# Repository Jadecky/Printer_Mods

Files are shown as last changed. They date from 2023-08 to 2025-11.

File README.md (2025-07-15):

# Kyle🇬🇧’s Printer Chaos, Mods & Configs 🛠️
Home to my various mods & QOL Updates for printers I've built, along with config backups.

---

## 🐝 My Printers
|**Name**|**Printer**|**Voron Serial**|**PFA Serial**|**Status**|
|-----|-----|-----|-----|-----|
| **Bee.Zero** | [Voron V0](https://vorondesign.com/voron0.2) | V0.1848 | N/A | On sabbatical (lazy bee vibes) |
| **Bee.Two** | [Micron R1](https://github.com/PrintersForAnts/Micron) | V2.6033 | M.055 | Current Workhorse 🐝 |
| **Bee.Three** | [StealthFork](https://github.com/PrintersForAnts/StealthFork) | SF.xxx | VT.xxxx | Work in Progress |
| **Bee.Four** | FireAnt | V2.xxxx | TBC | In Design Stage 🔥 |
| **Rex 🦖** | [Micron R1 - LDO Beta](https://github.com/PrintersForAnts/Micron) | V2.xxxx | M.202 | Tuning |

---

## 🛠️ Mods & Parts

### - [Micron Things](https://github.com/Jadecky/Printer-Mods/tree/main/Micron%2B)

### - [Voron V0 Things](https://github.com/Jadecky/Printer_Mods/tree/main/V0)

### - [Misc Items](https://github.com/Jadecky/Printer_Mods/tree/main/Misc%20Items)

---

## 🐜 Printers for Ants Items

### - [StealthFork](https://github.com/PrintersForAnts/StealthFork)
The one where Micron & Salad Fork had a baby...

### - [Colony Clacker](https://github.com/PrintersForAnts/ColonyClacker)
Tiny printer? Tiny door? Needs a satisfying clack

---

## 💾 Config Backups

### - [**Micron M.055**](https://github.com/Jadecky/Micron_Configs)

### - **Voron V0.1848** - Still need to setup auto commit 

### - **Micron M.202** - Still need to setup auto commit 

---

Most of these mods are also listed on my [Printables page](https://www.printables.com/@Jadecky3D/models) — if you like what you see, toss me a like or post a make to help me earn that gucci free spool 🧵 and keep the upgrades coming.

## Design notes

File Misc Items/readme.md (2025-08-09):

# Miscellaneous Items

The home of various bits that don't belong to one specific printer — or I just haven’t decided where they live yet.

| **Name** | **Description** |
|---|---|
| [**F623 Bearing Repacker**](https://github.com/Jadecky/Printer_Mods/tree/main/Misc%20Items/F623%20Bearing%20Repacker) | For repacking F623 or other M3 bearings with grease for optimal performance and longevity. |
| [**Micron really useful tool**](https://github.com/Jadecky/Printer_Mods/tree/main/Misc%20Items/Micron%20Really%20Useful%20Tool) | For locating your MGN7 rails & motor pulleys on Micron R1 |

*More random bits will appear here as they get designed or discovered...*

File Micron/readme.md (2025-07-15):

## 🔥 Micron R1 Mods

| **Mod** | **Info** |
|---|---|
| [**Matchstick Mounts**](https://github.com/Jadecky/Printer_Mods/tree/main/Micron/Micron/Matchstick%20Mounts)| MapleleafMakers awesome Matchstick Diffusers, slightly modded to point towards the bed in Micron |
| [**Micron Z Belt Clamp**](https://github.com/Jadecky/Printer_Mods/tree/main/Micron/Micron/Micron%20Z%20Belt%20Clamp)| Belt clamps to allow you to keep a bit of extra Z belt nice & neat. |
| [**ERCF 1515 Mounts**](https://github.com/Jadecky/Printer_Mods/tree/main/Micron/Micron/ERCF%201515%20Mount) | ERCF mounts for 1515 based printers |
| [**Micron Bed Standoff Sleeves**](https://github.com/Jadecky/Printer_Mods/tree/main/Micron/Micron/Micron%20Bed%20Stand%20Off%20Sleeves) | Aesthetic sleeve for your bed standoffs |
| [**Micron Nozzle Scrubber & Purge Bucket**](https://github.com/Jadecky/Printer_Mods/tree/main/Micron/Micron/Micron%2B%20Bambu%20Nozzle%20Scubber_with%20Purge%20Bucket) |
| [**Skirt Centre Accent Single Piece**](https://github.com/Jadecky/Printer_Mods/tree/main/Micron/Micron/Skirt%20Accent%20Single%20Piece)| 3x centre accent pieces merged into one for slightly cleaner look |
| [**Stealth Fan Grill**](https://github.com/Jadecky/Printer_Mods/tree/main/Micron/Micron/Stealth%20Fan%20Grills) | Slight modification to the stock Micron+ Fan Grills, reducing the visible accent areas for a more subtle, stealthy look |
| [**R1 Spool Holder Dual Colour**](https://github.com/Jadecky/Printer_Mods/tree/main/Micron/Micron/R1%20Spool%20Holder_Dual%20Colour) | Spool holder with accent PFA logo. |
| [**Display Bezel Accent Border**](https://github.com/Jadecky/Printer_Mods/tree/main/Micron/Micron/Display%20Bezel%20Border%20Accent) | Bezel for 4.3 display with small accent on the border and accent logo insert. For those who prefer less accent |

---

## 🕰️ Legacy Items - Micron R0

| **Mod** | **Info** |
|---|---|
[**3DPF**](https://github.com/Jadecky/3DPF/tree/main)|Carbon Filter/Bed Fan that fits between the bed extrusions. Now stock on Micron R1
[**KGLM Hex Z-Joint**]()|A slightly chonkier Z Joint to prevent cracking. Half hex shaped, rather than spherical. With Micron Logo or without.
[**MDC**]()|Magnetic Door Corners - Chonky Door corners/hinges to prevent your Micron door falling off. Uses screws/heatsets or optional VHB variant. Has a magnet in each corner to keep the door closed. 
[**Smol Hex Skirts**]()|Micron+ skirts with scaled down Hex's. 3.5" & 4.3" display & no display variants. Dual Keystone rear option.
[**Z Drive Belt Covers with Cable Access**]()|Allows cables for things such as Cameras or LEDs to be run down the extrusions and neatly through the Z Drive cover into the electronics bay.

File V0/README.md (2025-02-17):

## Various Voron V0 mods and things
Mod|Info
----|----
Rear DIN Rail Mount|As per title.. a DIN Rail mount for the rear of your V0, becuse VHB is nasty. 
Lower DIN Rail Mount|Again.. as per title, a DIN Rail Mount for the lower section of your V0, because VHB is grim. 
UHP Mount|Screw in mounts for a UHP200/24 for your V). Still allows bottom panel, because screw you VHB.

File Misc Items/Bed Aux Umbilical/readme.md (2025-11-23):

### Bed Aux Umbilical ###

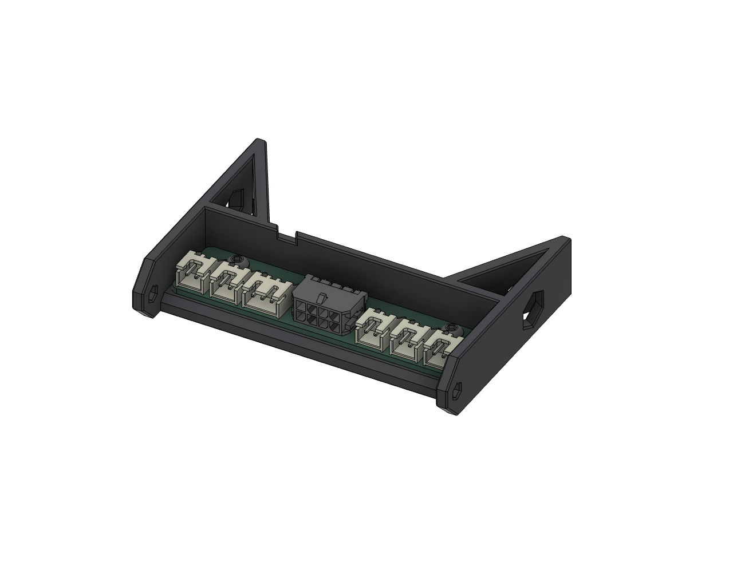
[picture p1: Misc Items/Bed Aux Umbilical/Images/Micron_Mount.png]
MicronMount


Originally designed for Micron R1, with a corresponding mount that replaces the Wago mount on the filter. 

These are included in the LDO Micron R1 Kit.

More information to follow.

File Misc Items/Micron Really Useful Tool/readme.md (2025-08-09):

# Really useful tool for locating MGN7 Rails and motor pulleys for Micron R1

### A / B Motor Pulleys

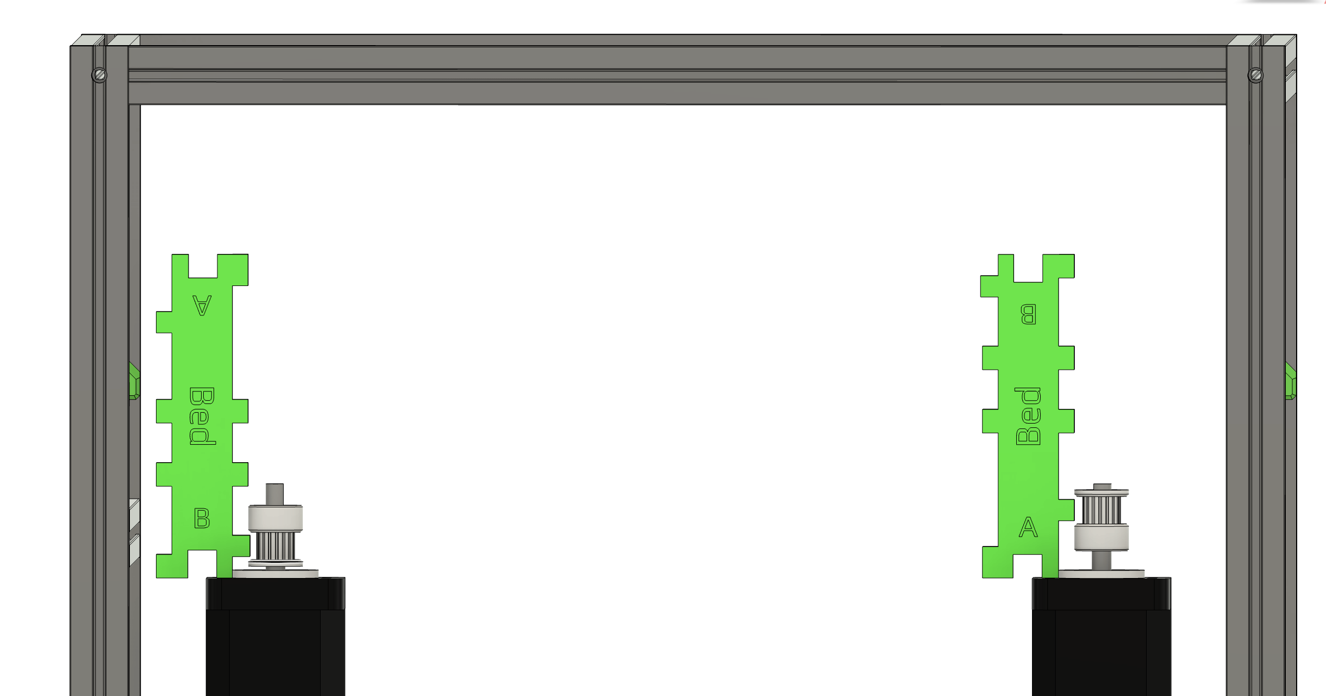
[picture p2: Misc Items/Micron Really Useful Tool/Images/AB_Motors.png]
AB Motor Pulley Example


### Z Motor Pulleys

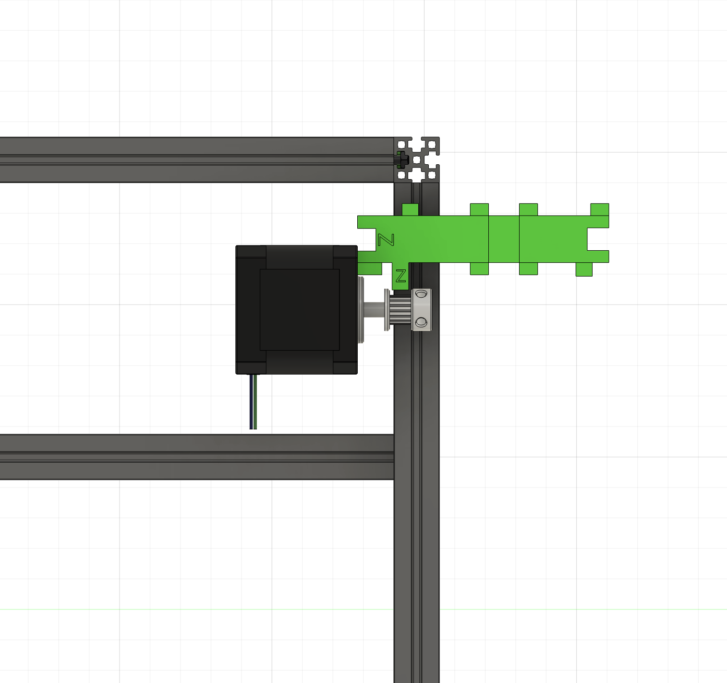
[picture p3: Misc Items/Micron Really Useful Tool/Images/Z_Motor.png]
Z Motor Pulley Example


### Y Rail

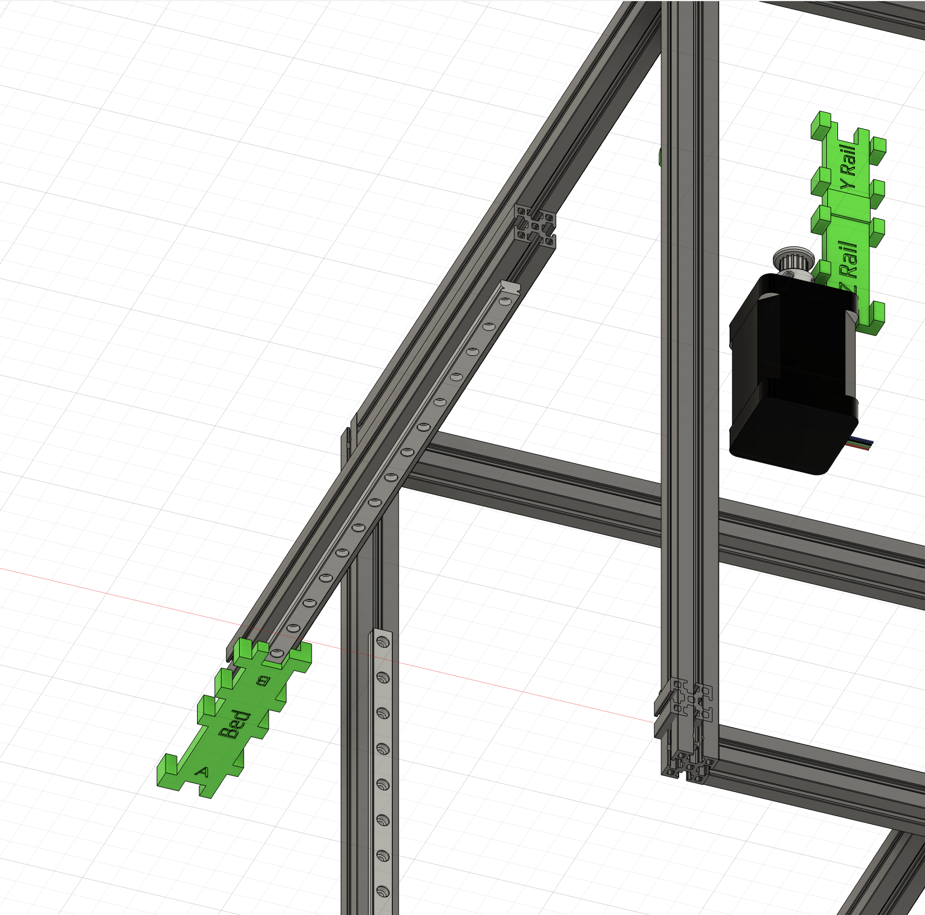
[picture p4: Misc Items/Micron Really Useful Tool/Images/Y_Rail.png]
Y Rail Example


### Z Rail

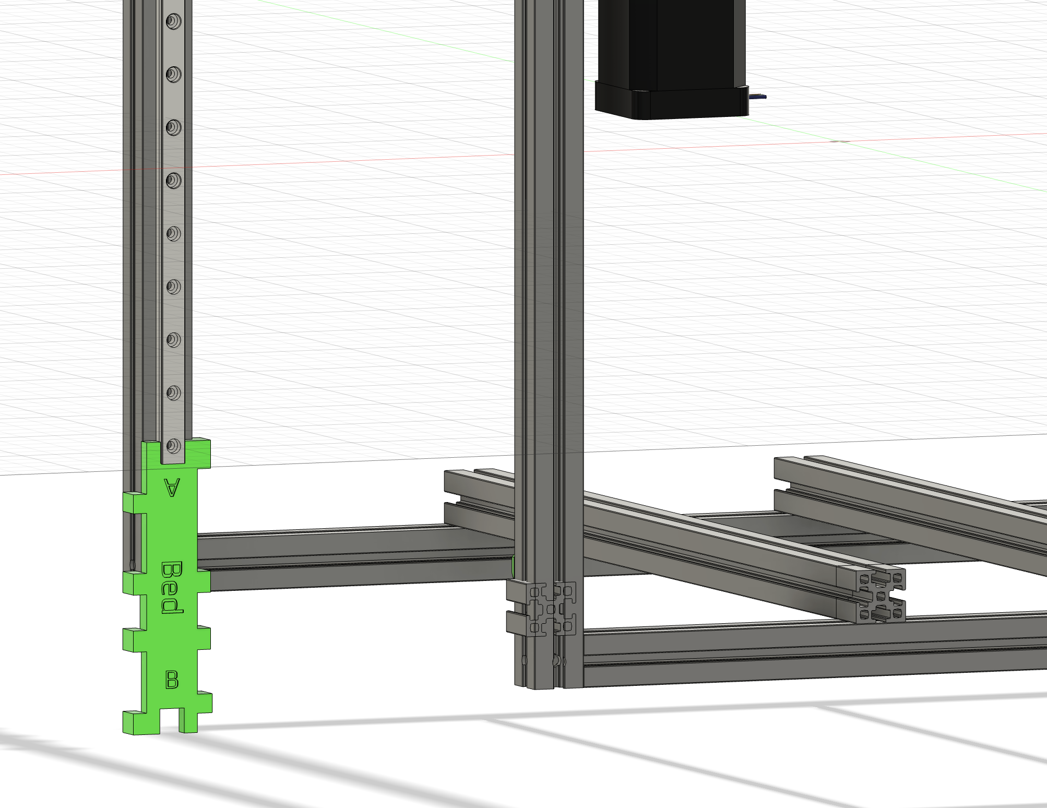
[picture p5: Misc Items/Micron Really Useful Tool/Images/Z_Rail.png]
Z Rail Example


### Bed Extrusion Location

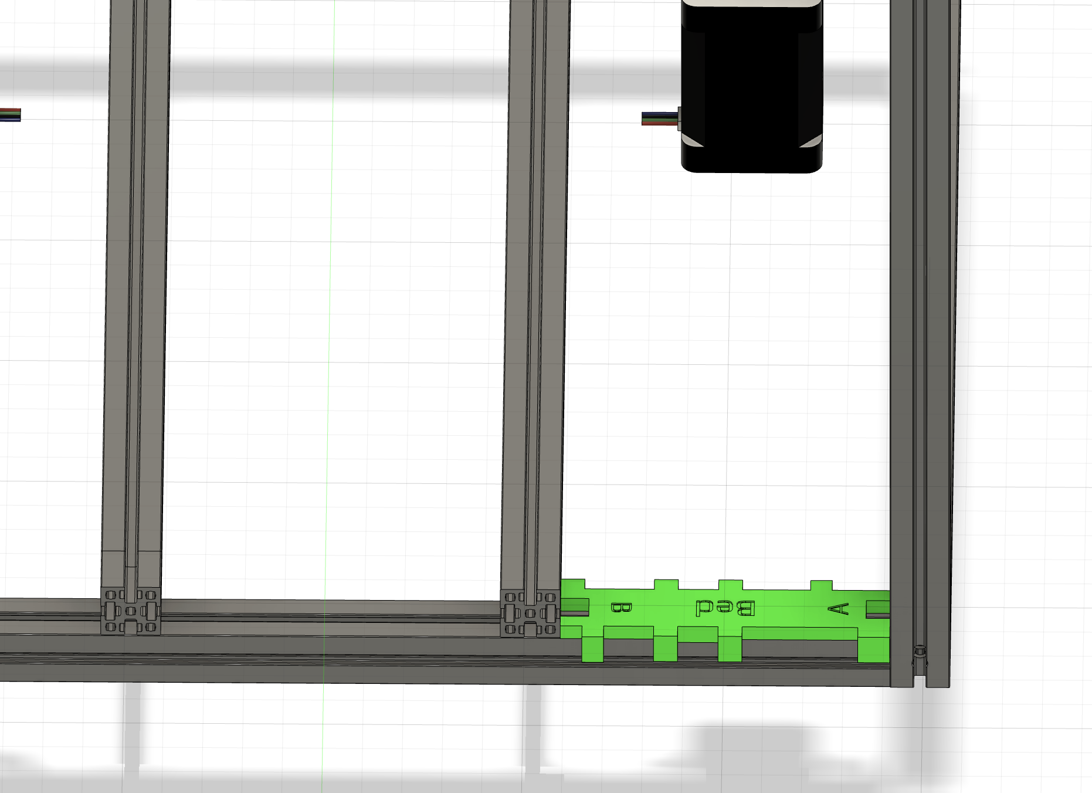
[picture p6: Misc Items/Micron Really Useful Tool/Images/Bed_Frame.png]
Bed Frame Example


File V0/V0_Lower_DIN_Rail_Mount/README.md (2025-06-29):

## Lower DIN Rail Mount for the Voron V0.2

Utilises the existing M3 Nut and hole for mounting the skirt. 

Can be mounted in upto 3x different locations, using the different skirt mounts. 

Has an optional tension screw to prevent rattling of the DIN rail.

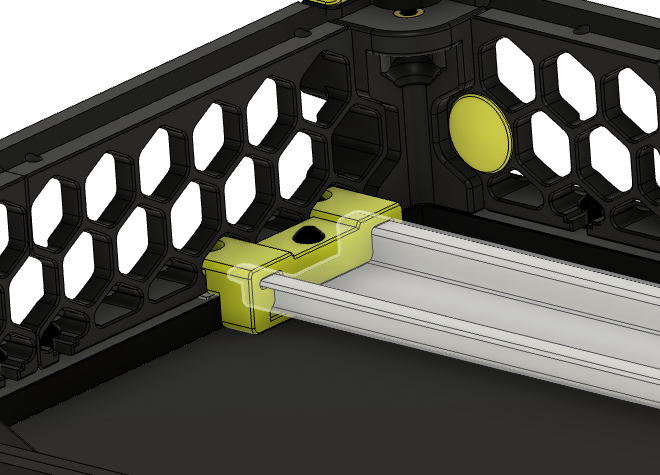
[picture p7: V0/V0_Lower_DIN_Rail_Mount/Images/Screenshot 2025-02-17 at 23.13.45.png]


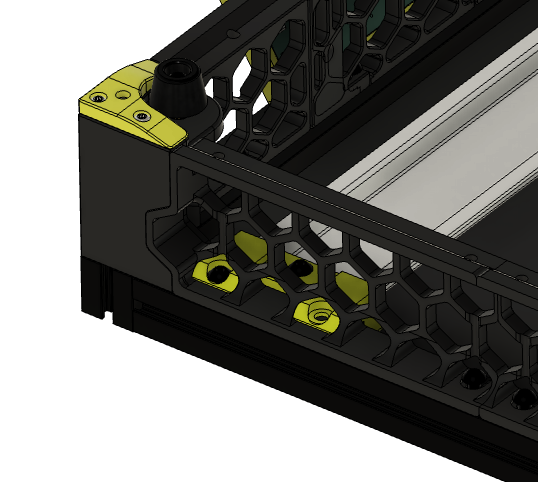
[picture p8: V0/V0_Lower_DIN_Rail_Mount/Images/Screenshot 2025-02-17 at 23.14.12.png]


## BOM
Qty|Item|Links/Comments
---|----|---
6x|M3x8 BHCS|[AliExpress](https://s.click.aliexpress.com/e/_Ezk8fMo)
1x|M3 Threaded Heatset Insert|[AliExpress](https://s.click.aliexpress.com/e/_ExdRmeo)
1x|DIN Rail 195mm|[AliExpress](https://s.click.aliexpress.com/e/_EHIRMhQ)

## Printing
Print using Voron standard print settings.

Parts are orientated in the correct orientation.

No Supports required. 

## Version History

### 17-Feb-2025
Initial Upload

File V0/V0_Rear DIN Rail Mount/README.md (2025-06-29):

## Rear DIN Rail Mount for the Voron V0

Initially based on [Chirpy's DIN Rail Mount](https://github.com/chirpy2605/voron/tree/main/V0/v0.2_Stuff#din-rail-mounts)

Added more stealth, more bestagons, and optional tension screw to prevent rattling of the rail. 

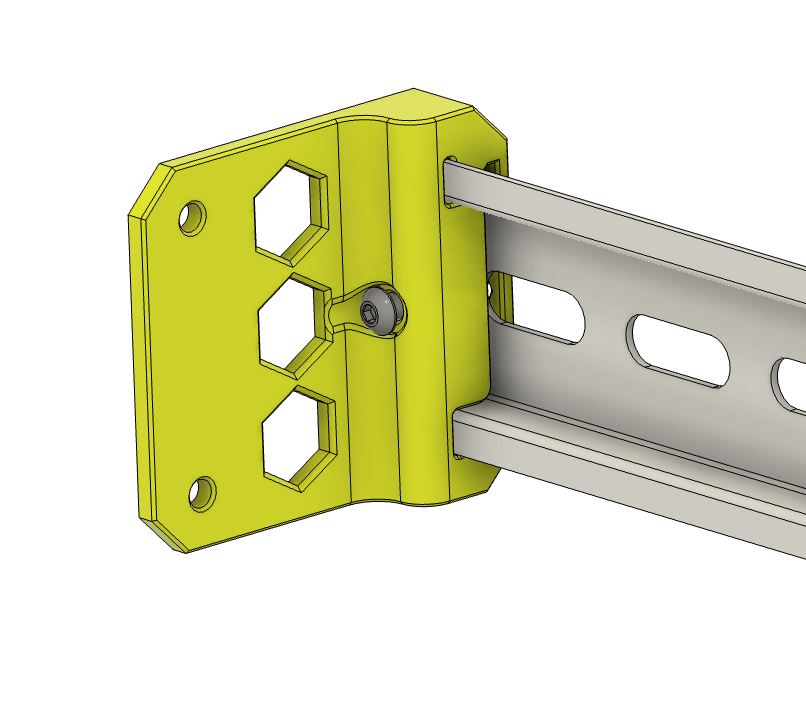
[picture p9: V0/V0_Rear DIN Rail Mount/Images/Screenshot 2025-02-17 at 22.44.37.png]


## BOM
Qty|Item|Links/Comments
---|----|---
4x|M3x8 BHCS|[AliExpress](https://s.click.aliexpress.com/e/_Ezk8fMo)
2x|M3x12 BHCS|[AliExpress](https://s.click.aliexpress.com/e/_EuzIPxm)
2x|M3 Threaded Heatset Insert|[AliExpress](https://s.click.aliexpress.com/e/_ExdRmeo)
1x|DIN Rail 195mm|[AliExpress](https://s.click.aliexpress.com/e/_EHIRMhQ)

## Printing
Print using Voron standard print settings.

Parts are orientated in the correct orientation.

No Supports required. 

## Version History

### 17-Feb-2025
Initial Upload

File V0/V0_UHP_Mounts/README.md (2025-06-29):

## UHP 200/24 PSU Mount for Voron V0

### Allows you to mount a UHP 200/24 without the need for VHB, whilst still being able to 110% complete your printer with a bottom panel. 

Utilises the existing M3 Nut and hole for mounting the skirt. 

Can be mounted in upto 3x different locations, using the different skirt mounts. 

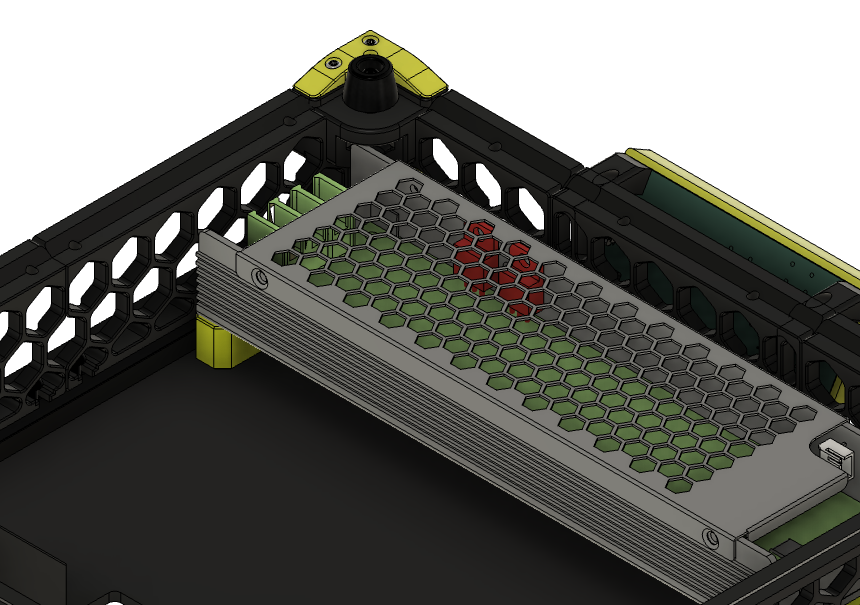
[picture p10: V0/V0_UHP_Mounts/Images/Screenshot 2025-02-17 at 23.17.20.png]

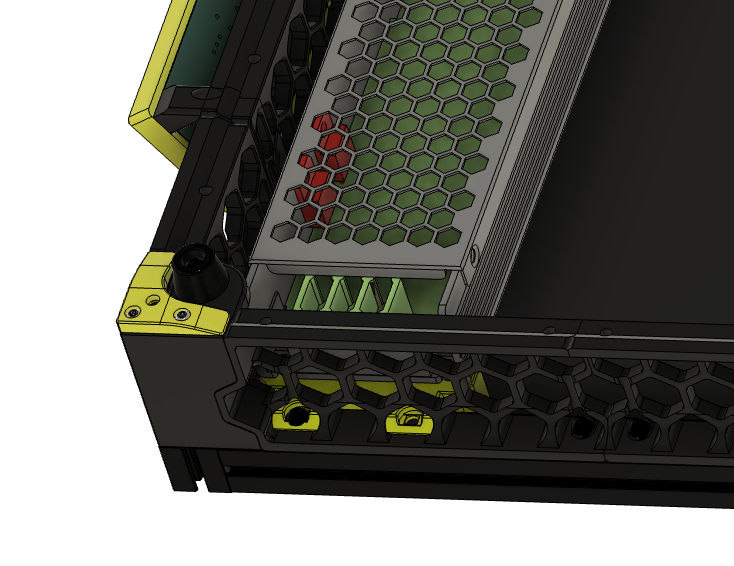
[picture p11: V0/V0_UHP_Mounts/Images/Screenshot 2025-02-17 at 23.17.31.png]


## BOM
Qty|Item|Links/Comments
---|----|---
4x|M3x12 or M3x14 BHCS|[AliExpress](https://s.click.aliexpress.com/e/_EuzIPxm)
4x|M3 Threaded Heatset Insert|[AliExpress](https://s.click.aliexpress.com/e/_ExdRmeo)
1x|DIN Rail 195mm|[AliExpress](https://s.click.aliexpress.com/e/_EHIRMhQ)

## Printing
Print using Voron standard print settings.

Parts are orientated in the correct orientation.

No Supports required. 

## Version History

### 17-Feb-2025
Initial Upload

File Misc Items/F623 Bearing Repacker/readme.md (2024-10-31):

## F623 Bearing Repacker
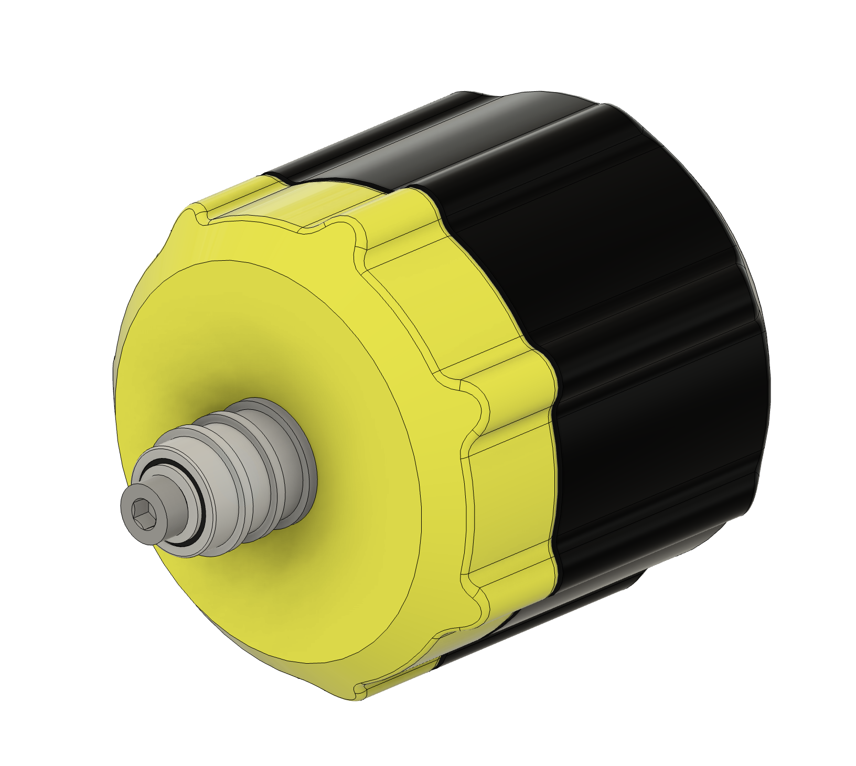
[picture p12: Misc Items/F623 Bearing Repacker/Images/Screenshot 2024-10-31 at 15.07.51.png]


'Remix' of the original [Bearing Repacker](https://github.com/Annex-Engineering/Misc_Designs/tree/master/Bearing_Repacker) from [Annex-Engineering](https://annex-engineering.eu) for the smaller F623 Bearings found in the Voron V0 and 3D Printers for Ants. 

Now has an M3 heatset, rather than a nut, to prevent unwanted handling of grease covered, sticky nuts. 
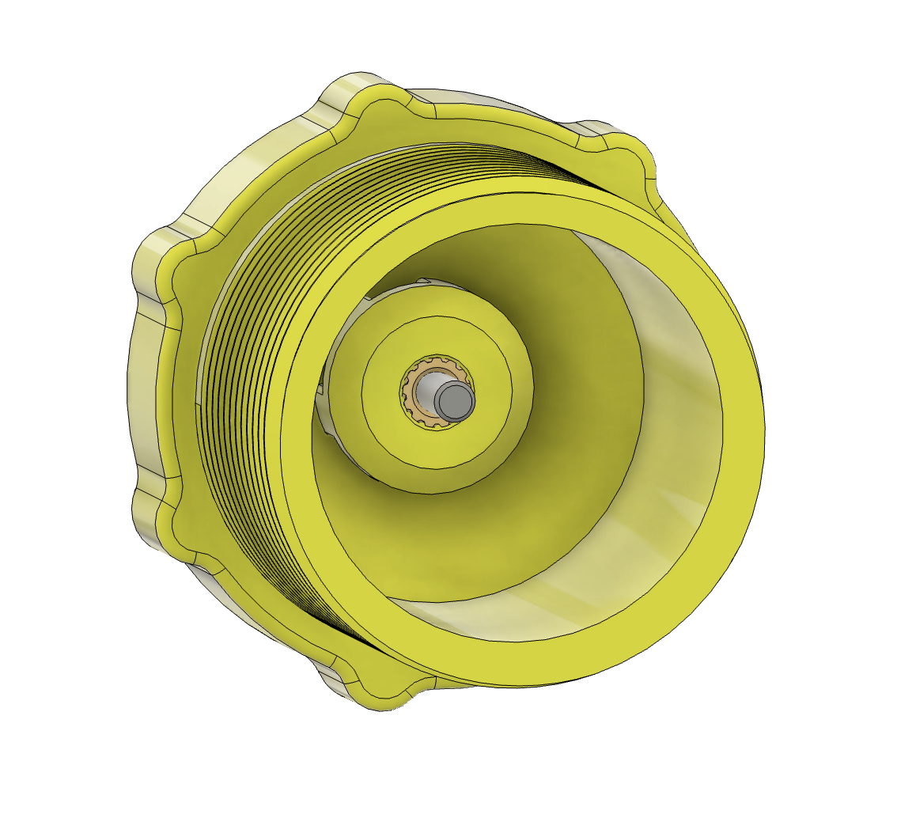
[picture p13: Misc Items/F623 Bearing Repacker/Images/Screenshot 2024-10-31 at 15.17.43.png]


If using a flanged bearing, the flange should go against the printed part. (See first image)

Don't forget to remove and replace the seals before and after repacking withgrease.

# BOM
Qty|Item|Notes
---|----|---
1x|`Top_x1.stl`|
1x|`[a]_Bottom_x1.stl`|
1x|M3x30SHCS|Length varies depending on number of bearings
1x|M3 Heatset|
1x|M3 Shim Washer|Optional, but nice between the SHCS and the Bearing
Nx|Grease of choice
Nx|F623 Bearings|or similar M3 bearings
Nx|Gloves|Horrible stuff is grease.

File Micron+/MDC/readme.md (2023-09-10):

# MDC - Magnet Door Corners
Chonky door hinges & corners that are mounted with screws, and have a magnet in each corner.

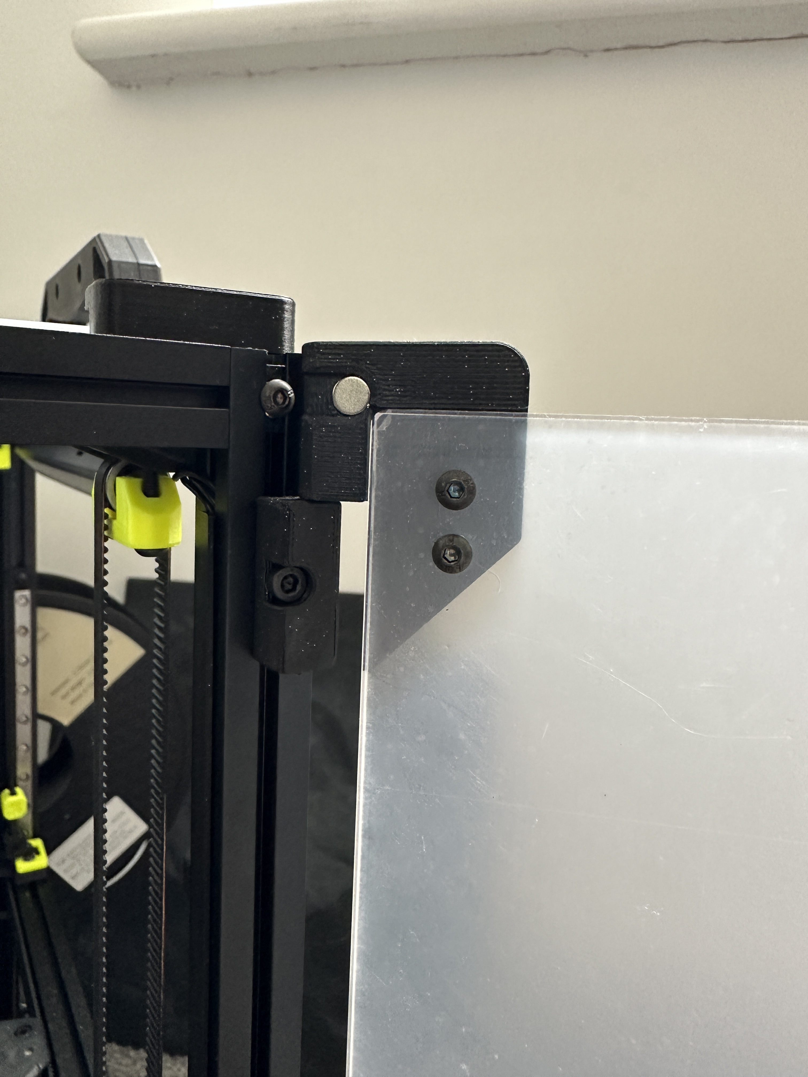
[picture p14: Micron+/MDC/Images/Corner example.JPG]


## Disclaimer

**The primary design of this modification requires you to drill your door panel. Drill guides have been provided.**

**Whilst every effort has been made to ensure this goes as smoothly as possible, it is your responsibility to measure and double check before adding holes to your panel. Please check, double check, and tripple check prior to drilling.**

**If you aren't comfortable/confident enough to drill your panel, there is a DXF so you can get one cut, there is also a VHB version, although this is currently untested.**

## Why is this a thing?

There are several reasons this modification has come about:

- I needed to use the left extrusion to feed cables to the camera, you can't do this with the stock magnet holders being screwed to that extrusion. This modification puts a magnet in each corner instead.

- There were several reports of the larger Micron+ door falling off due to the small contacct area for VHB tape on the stock hinges.

- My OCD likes each corner on the front to look the same. The new hinges have taken the same design as the left hand corners of the door.

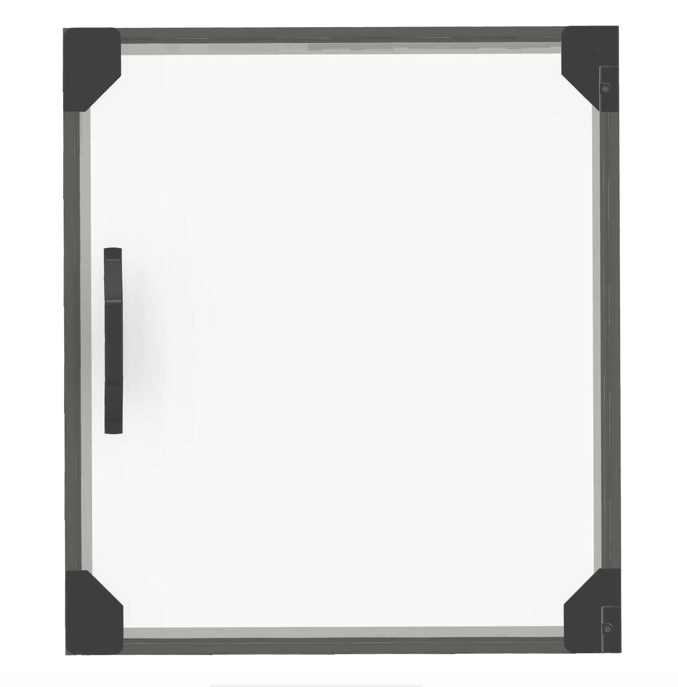
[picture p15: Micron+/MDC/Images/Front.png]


## BOM
Qty |Part|Notes
---|----|---
1x|1mm / 1.5mm drill bit|For drilling pilot holes in the panel
1x|3mm drill bit|For finialising the holes in the panel
10cm|Masking/painters tape|For marking the centre of the panel for drilling the handle holes 
4x|6x3 Magnets|N52 recommended for a nice grab 
2x|M3x8mm SHCS|To mount the hinges to the frame
13x|M3x6mm BHCS|10x for mounting printed parts to door, 3x for magnets in TL, TR & BL corners. *(If using VHB, only 3x required)*
10x|M3 Washer|Optional, but good practice when mounting the printed parts to door panel
10x|Voron Spec Brass Heatset Inserts|M3x5Dx4.5W *(Not required for VHB version)*
2x|M3x35 *minimum* BHCS|For hinges, M3x40, M3x45 will also work
1x|M3x4mm|For BR Magnet. Unfortunately anything larger will interfere/mark the extrusion.
6x|M3 Nut|4x for corner magnets, 2x for mounting hinges to frame. 

## Printed Parts BOM
**Heatset Version**
Qty|STL
---|---
1x|Bottom_Hinge_Door_Mount
1x|Bottom_Left_Door_Corner
1x|Heatset_Door_Handle
2x|Hinge_Frame_Mount
1x|Top_Hinge_Door_Mount [*]
1x|Top_Hinge_Door_Mount_MMU [*]
1x|Top_Left_Door_Corner
**Drill Guides**
1x|Drill_Guide_BL
1x|Drill_Guide_BR
1x|Drill_Guide_Handle
1x|Drill_Guide_TL
1x|Drill_Guide_TR

[*] Choose either/or

**VHB Version**
Qty|STL
---|---
Qty|STL
2x|Hinge_Frame_Mount
1x|VHB_Bottom_Hinge_Door_Mount
1x|VHB_Bottom_Left_Corner
1x|VHB_Top_Hinge_Door_Mount [*]
1x|VHB_Top_Hinge_Door_Mount_MMU [*]
1x|VHB_Top_Left_Corner

[*] Choose either/or

## Drill Guides

You should use a 1mm/1.5mm pilot drill initially, then move up to a 3mm drill bit. 

Drill slowly without too much pressure, let the drill bit do the work, and ensure you have a solid base such as a piece of wood. This should prevent cracking your panel. 

The drill guides are marked with which corner they should be placed. They go in the same orientation as the hinges, so facing you when looking at the front.

**Flat Surface | Panel | Drill Guide.**

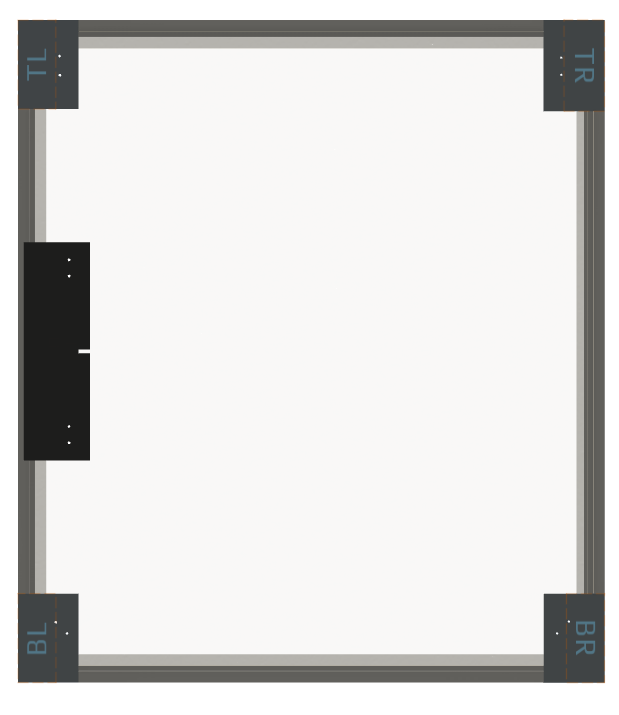
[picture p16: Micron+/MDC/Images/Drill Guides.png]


When locating the handle drill guide, use a piece of masking tape (mine still has the protective film on below) to mark the centre line. There is a recess in the drilling guide that will line up with this centre line:

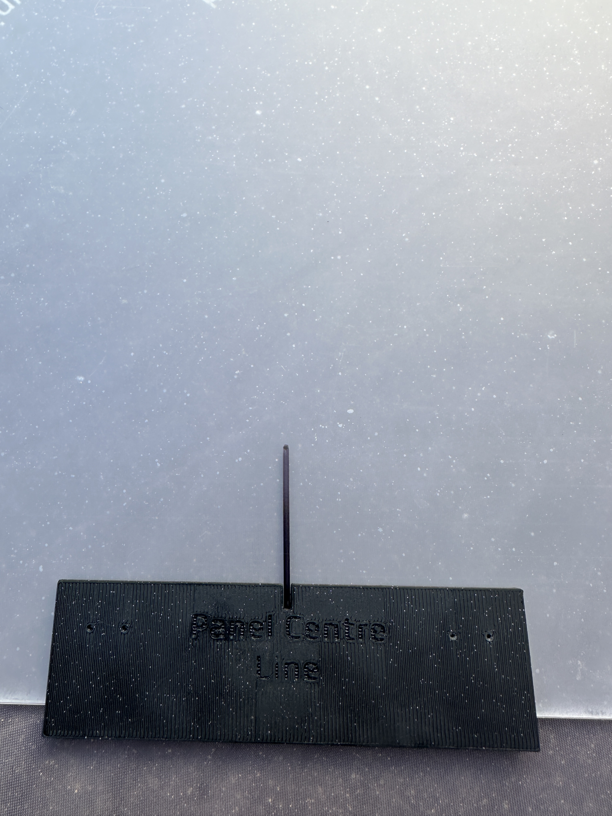
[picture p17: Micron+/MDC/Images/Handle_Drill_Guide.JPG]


## Mounting to the printer

Each corner piece has a recess for 1 6x3 magnet, and 2x holes for a voron spec heatset insert. 

- Insert the 2x heatsets into each corner, and the 4x heatsets into the handle. (If using VHB version only the magnets are required).

(I suggest sticking the magnet to the end of a screw, then using the screw to push the magnet home).

Glue shouldn't be required, but you can add a drop of CA/Super glue, should you wish to.

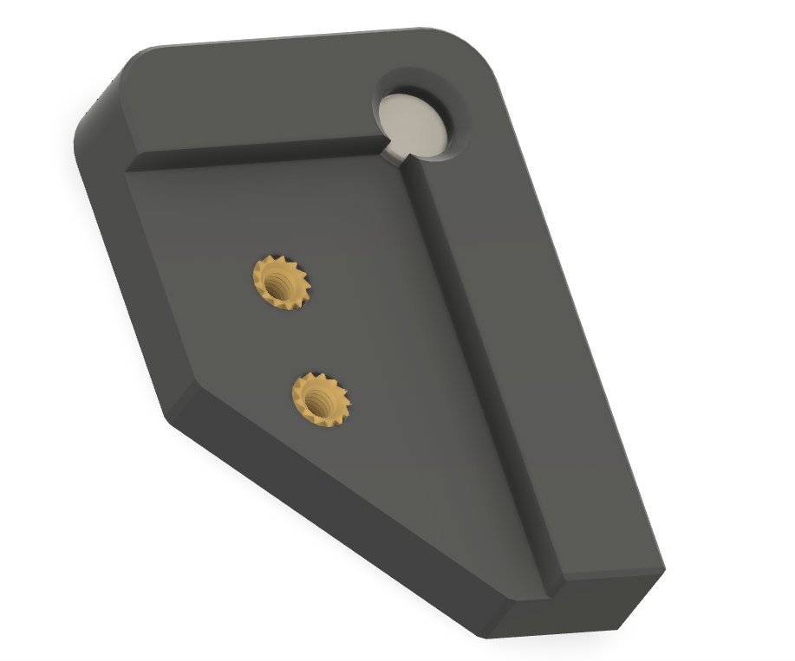
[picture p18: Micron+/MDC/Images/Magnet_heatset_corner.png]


- Insert an M3x35mm *minimum* screw into the the bottom of the hinge_frame_mount. (Anything upto M3x45 can be used here).

- Mount the lower Hinge_Frame_Mount to the right extrusion using an M3x8 SHCS & M3 Nut, leave loose for now. 

- Insert an M3 Nut with an M3x4mm BHCS, above the Lower hinge_frame_mount. This will be used to hold the door closed with the magnet you just inserted for the hinge.

- Now repeat fot the top hinge. (Upto an M3x10mm BHCS can be used for the magnets on TL, TR & BL corners as the screw will go through the access hole in the extrusion).

- Place the ```bottom_hinge_door_mount``` & ```top_hinge_door_mount``` over the relevant ```hinge_frame_mount``` and align the screws in the extrusion with the magnets.

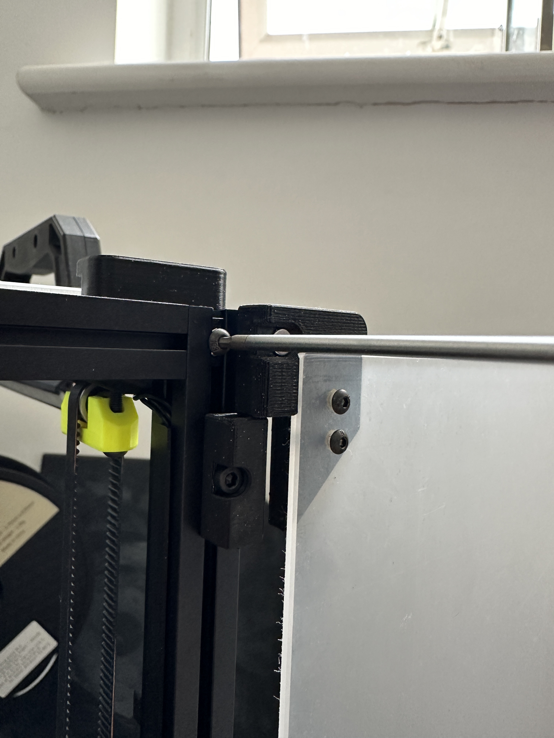
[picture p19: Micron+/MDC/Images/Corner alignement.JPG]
 

- Repeat the M3 BHCS twice on the left extruision and align with the TL & BL corners.

- Mount the printed pieces to the door using M3x6mm BHCS and an optional M3 Washer.

- Check alignment of your hinge mounts and magnet screws and tighten everything up. 

# Feedback

I have added this to my printer without any issues. @Staticanime has also tested this without issue. If you have any feedback/advice please discuss in the [kyle_gb channel](https://discord.com/channels/825469421346226226/1132795892810907748) on the [Doomcube Discord.](https://discord.gg/doomcube)

# To Do / Change Log
- Add hardware to CAD
- Tidy up CAD

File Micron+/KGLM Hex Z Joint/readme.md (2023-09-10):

# KGLM Hex Z-Joint

A slightly chonkier Z Joint to prevent cracking. Half hex shaped, rather than spherical. With Micron Logo or without.

(For the logo version, print the top layer slooooow)

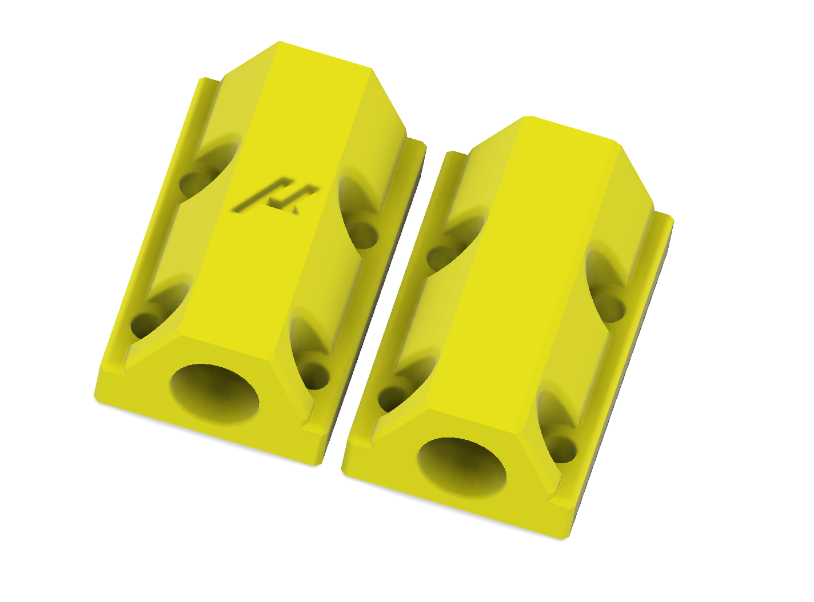
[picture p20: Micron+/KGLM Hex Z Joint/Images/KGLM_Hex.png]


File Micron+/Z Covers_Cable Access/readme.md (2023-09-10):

# Z Drive Belt Covers with Cable Access

Allows cables for things such as Cameras or LEDs to be run down the extrusions and neatly through the Z Drive cover into the electronics bay. 

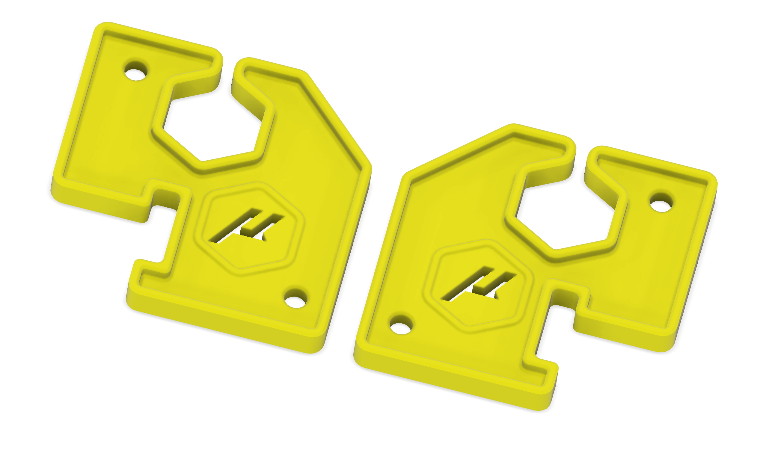
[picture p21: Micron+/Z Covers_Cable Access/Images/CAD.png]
CADIMAGE


Modelled here by @staticanime

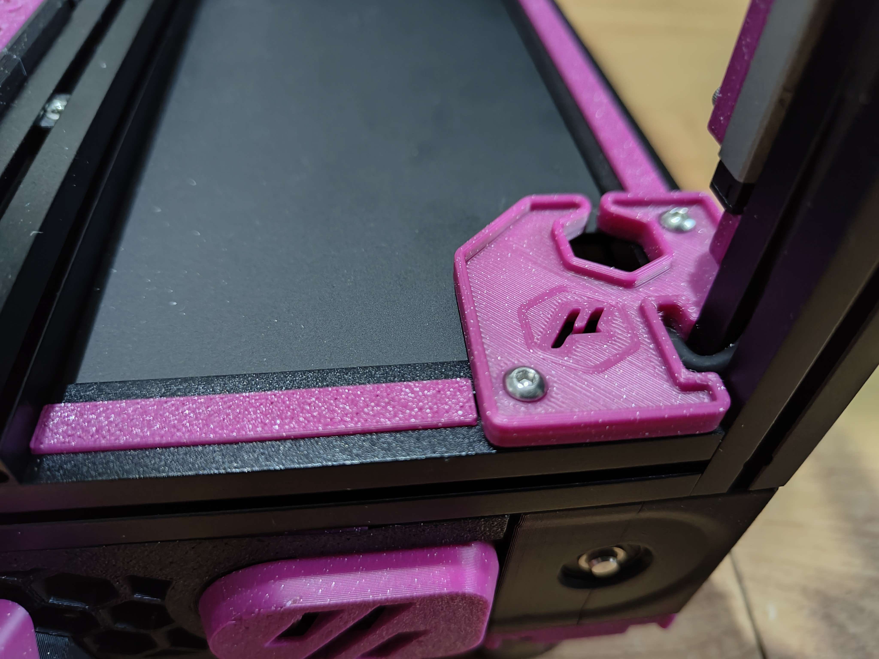
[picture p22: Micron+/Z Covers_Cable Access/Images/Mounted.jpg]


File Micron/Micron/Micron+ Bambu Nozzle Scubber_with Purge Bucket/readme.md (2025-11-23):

# 🧽 Micron+ Nozzle Scrubber & Purge Bucket  
### *Because even your nozzle deserves a spa day.*

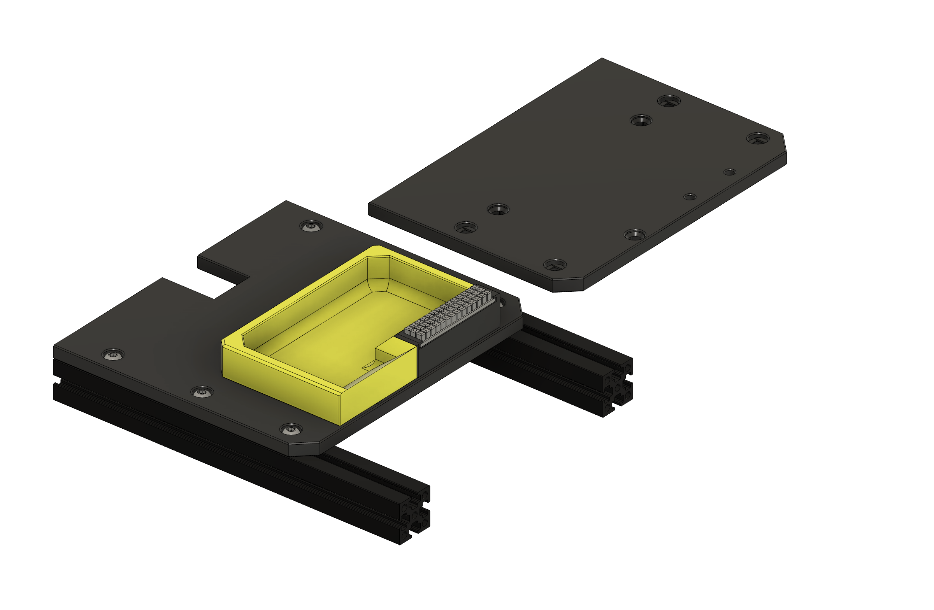
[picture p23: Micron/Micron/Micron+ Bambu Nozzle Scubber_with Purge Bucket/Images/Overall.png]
Overall View


Keep your nozzle tidy and your purge blobs contained with this magnetic bucket and silicone scrubber combo — easy to install, easy to empty, and deeply satisfying to use.

Now available with the silicone brush on right (original) or left. Placing it on the left reduces any fouling of the toolhead on the Z Chain.
Thanks to `@vince M.213` for the suggestion to have the new brush on the left variant. 

There is also a different version of the Bucket, and Brush holder for LDO kits as they come with 15mm standoffs for the bed rather than M4 Knurled nuts. 

**IMPORTANT** If using the brush on the left variant, you will need to adjust the co-ordinates in the provided macros if you are using them. 
---

## 🧼 Features  
- 🐜 Designed for **Micron+** 
- 🧲 **Magnet & screw bucket fitment** for secure mounting and quick removal  
- 🧽 Uses **Bambu Lab A1-style silicone nozzle scrubber**  
- ⚙️ 3x base options included: `base_no_chain`, `base_boop`, & `base_stock` for flexible installs

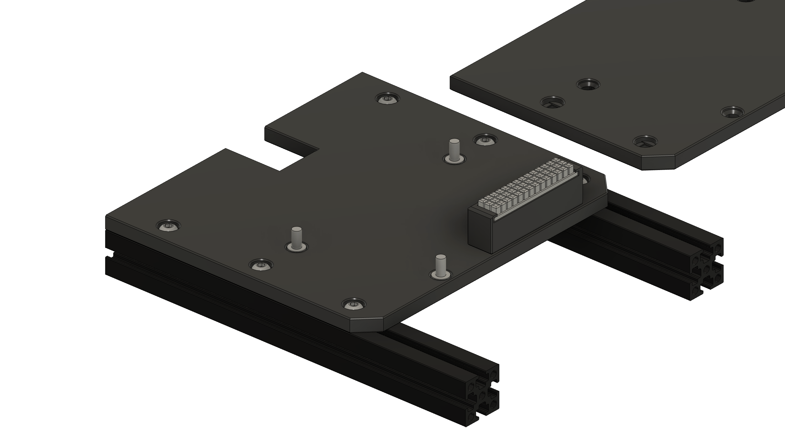
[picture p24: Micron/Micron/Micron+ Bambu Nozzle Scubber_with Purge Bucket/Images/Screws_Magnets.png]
Screws & Magnets


---

## 📦 Bill of Materials (BOM)

| Qty | Item | Notes / Link |
---|----|----
x7|M3x6 BHCS|[Aliexpress](https://s.click.aliexpress.com/e/_EuZgLr4)
x6|M3 Hex Nuts|[Aliexpress](https://s.click.aliexpress.com/e/_EwAgnb8)
x6|6mm x 3mm N52 Magnet|[Aliexpress](https://s.click.aliexpress.com/e/_EQ4GZeE)
x2|4x5 Heatset Insert (Voron spec)|[Aliexpress](https://s.click.aliexpress.com/e/_EuBQ66m)
1x|Bambu Lab A1 Nozzle Scrubber|[Aliexpress](https://s.click.aliexpress.com/e/_Ev16llx)

---

## 📅 Version History

### 23-Nov-2025
- Added `Brush_Holder_LDO_Kit_x1.stl` and `[a]_Bucket_LDO_Kit_x1.stl` for use with LDO Micron R1 Kits
- Added new variat with the brush on the left, rather than the right
- Updated CAD to include the above changes, now v15

### 16-Jun-2025
- Added `base_stock.stl` for stock Micron bed location
- Redesigned front edge with better cleance for earth cables screwed to build plate
- Reduced mountnig screws from x6, to x4
- Relocated rear mounting screws, to allow use of stock printed bed extrusion mounts, or extended 1515 extrusions
- Typo in `nozzle_poop.cfg` corrected
- Updated CAD to v13

### 05-Jun-2025
- Added `nozzle_brush.cfg`
- Added `nozzle_poop.cfg`

### 20-Nov-2024  
- Initial release  
- Added `base_no_chain.stl` for alternate setups  

---

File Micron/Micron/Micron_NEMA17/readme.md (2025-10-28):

# NEMA17 A/B Motor Upgrade for you Micron

Overall View

---

## 🔧 Overview 
New A/B motor mounts for your Micron, that are designed to use NEMA17 motors, with accompanying dual sheer bearing holders. 
Full bed travel is retained, however you might need to readjust the location of your bed towards the front slightly. (Approx 4mm)

Bearing mount retainers can be found in the Micron repo **[here](https://github.com/PrintersForAnts/Micron/tree/main/STLs/Gantry/AB_Drives/double_shear_mounts)**

---

## 🪛 Changes from Stock
- Bearing Mounts require 2x **M3x30 SHCS**
- A/B Support Extrusion requires shortening slightly to **168mm**

---

## 🖨️ Print Settings  

**All STLs should be pre-oriented for printing.**

- **Material:** ABS or ASA
- **Layer height:** 0.20 mm (including first layer)
- **Wall count:** 4
- **Extrusion width:** 0.40 mm (forced)
- **Top/bottom solid layers:** 5
- **Infill:** 40% (Grid, Gyroid, Honeycomb, Triangle, or Cubic)
- **Supports:** Not required

---

## 🗓️ Version History  

### 28 Oct 2025  
- 🆕 Initial release  

---

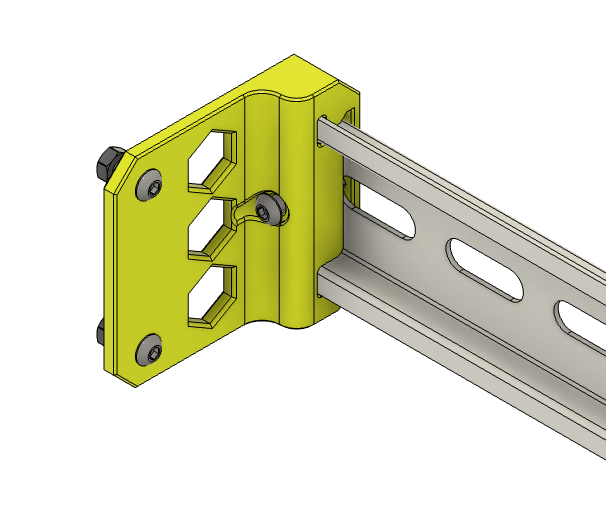
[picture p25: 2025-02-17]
V0/V0_Rear DIN Rail Mount/Images/Screenshot 2025-02-17 at 22.47.20.png

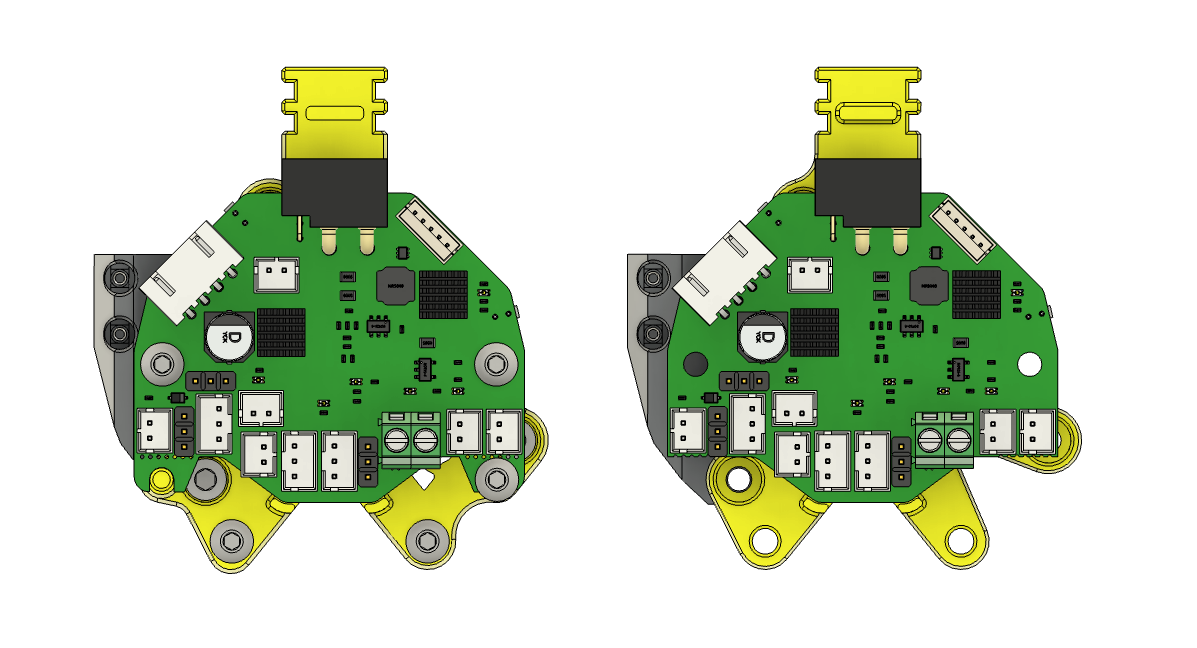
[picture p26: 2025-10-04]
Micron/Micron/AntHead_NH36 Mount/Images/Tabs_NoTabs.png

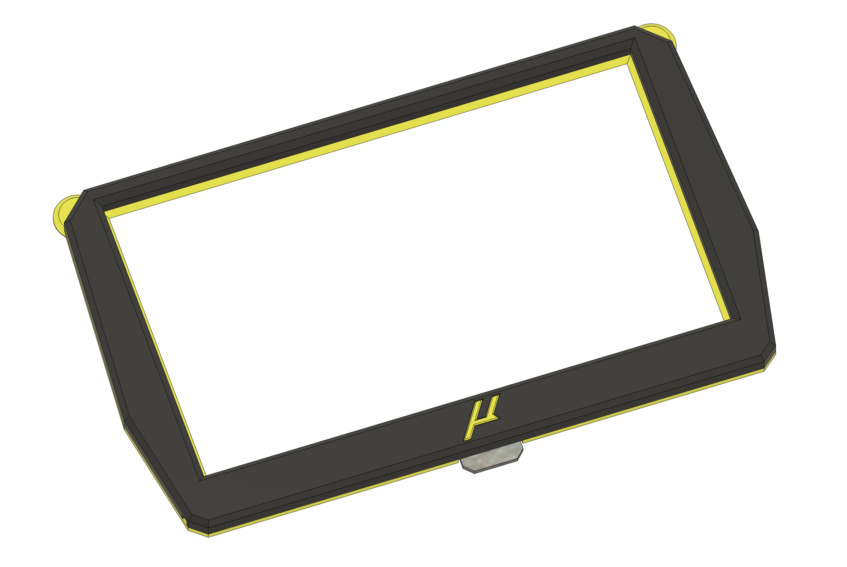
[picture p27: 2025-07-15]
Micron/Micron/Display Bezel Border Accent/Images/CAD.png

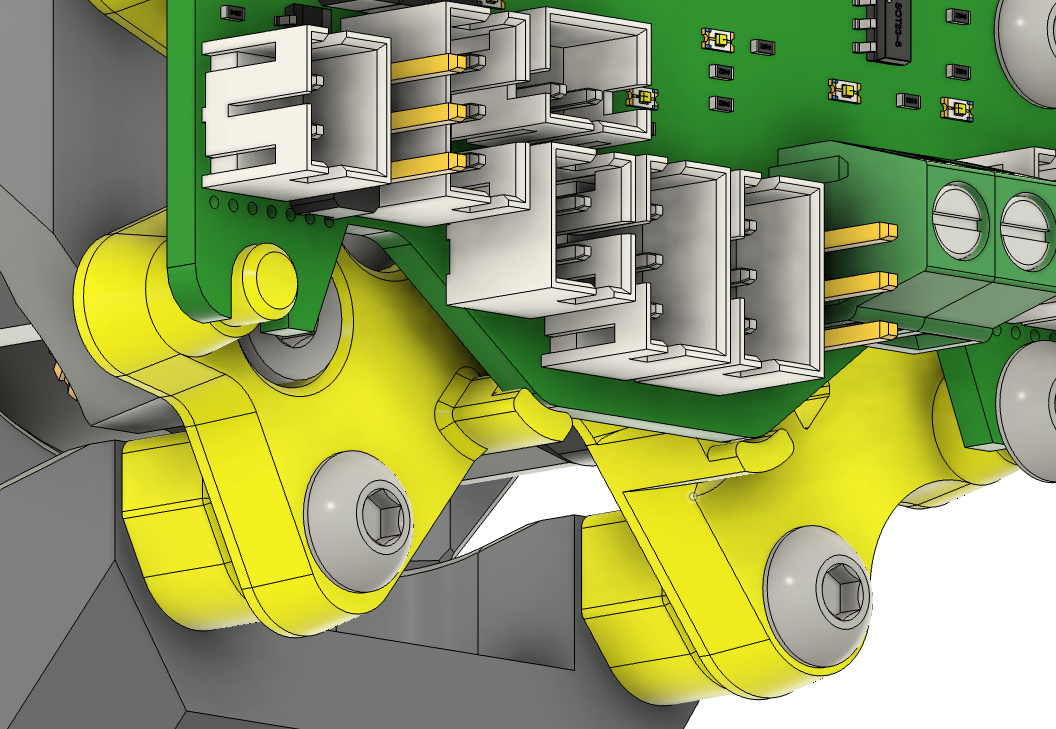
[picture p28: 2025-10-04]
Micron/Micron/AntHead_NH36 Mount/Images/Built_in_support_lower.png

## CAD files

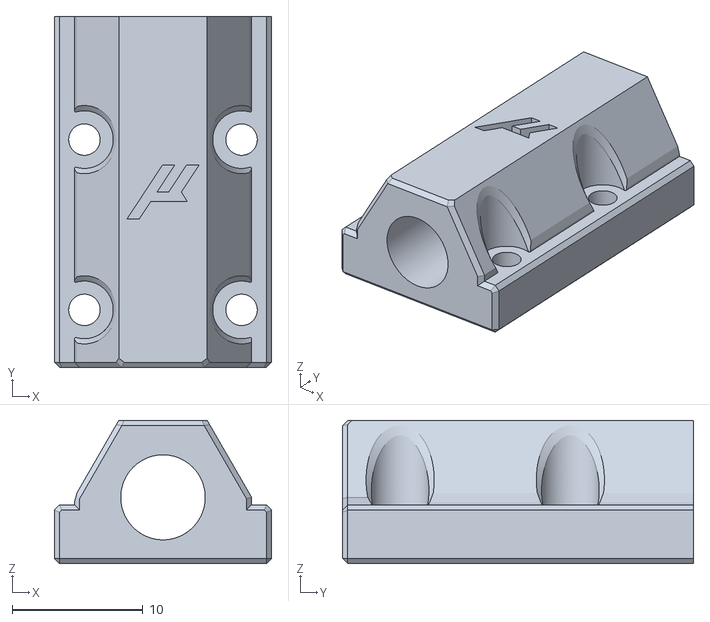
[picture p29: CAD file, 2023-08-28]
Micron+/KGLM Hex Z Joint/[a]_Z_Joint_Hex_Logo_x4.stl
16.6 x 26.8 x 11.0

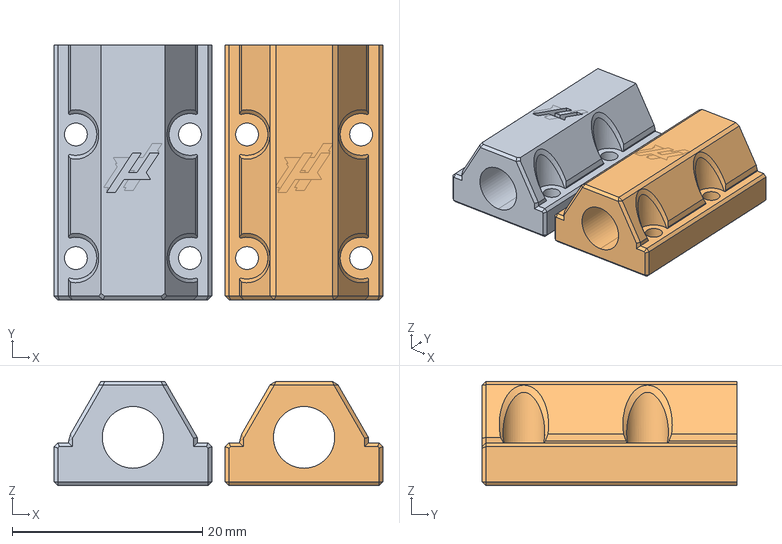
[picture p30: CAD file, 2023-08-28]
Micron+/KGLM Hex Z Joint/CAD/KGLM_Hex_Z_Joint.step
34.6 x 26.8 x 11.0 mm
Z_Joint_Hex_Logo
Z_Joint_Hex_No_Logo

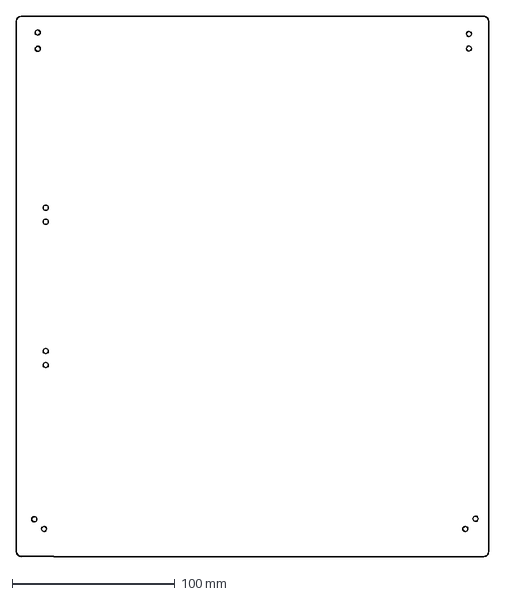
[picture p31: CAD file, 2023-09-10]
Micron+/MDC/DXF/MDC_Door.dxf
290.0 x 332.1 mm

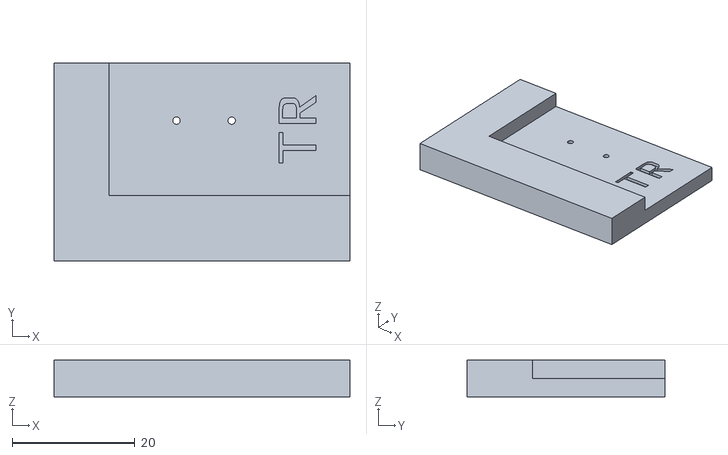
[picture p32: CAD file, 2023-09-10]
Micron+/MDC/STLs/Heatset Version/Drill Guides/Drill_Guilde_TR.stl
48.3 x 32.2 x 6.00

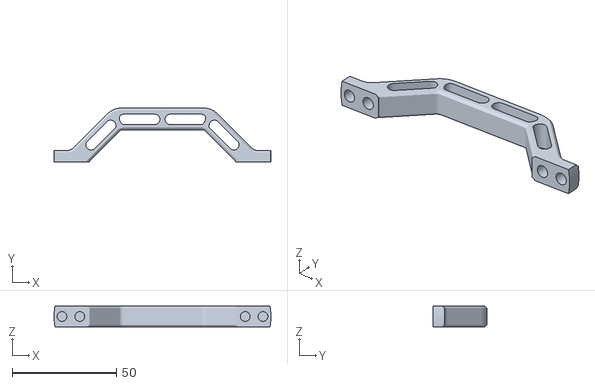
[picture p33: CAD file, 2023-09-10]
Micron+/MDC/STLs/Heatset Version/Heatset_Door_Handle.stl
104.3 x 26.0 x 10.0

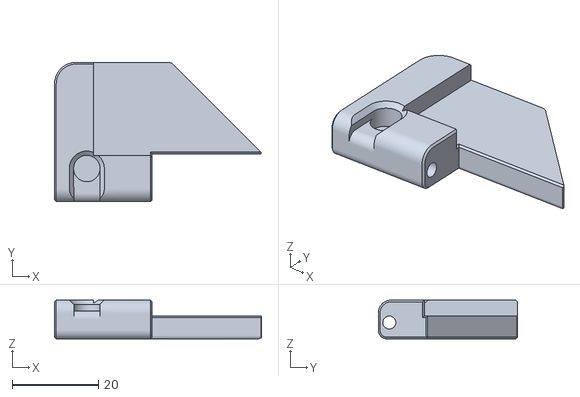
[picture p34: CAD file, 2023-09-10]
Micron+/MDC/STLs/VHB Tape Version/VHB_Top_Hinge_Door_Mount.stl
47.9 x 32.2 x 9.00

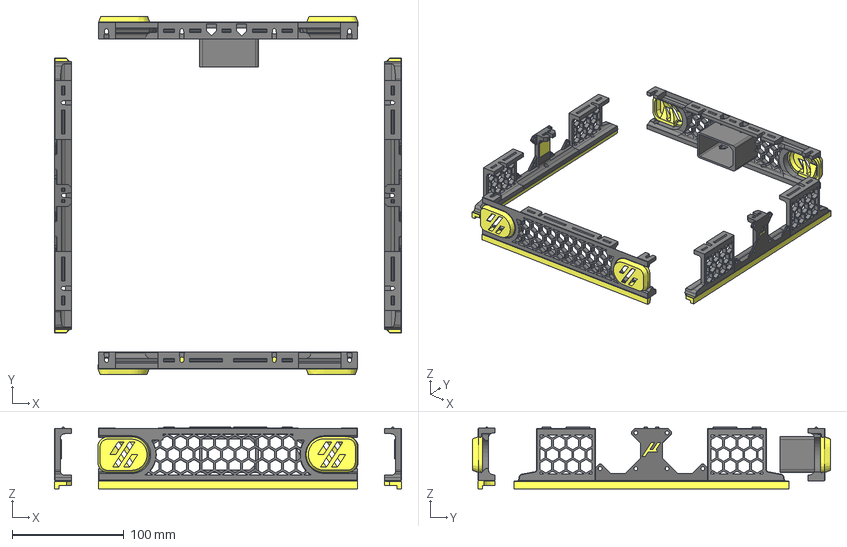
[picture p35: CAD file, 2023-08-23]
Micron+/Smol Hex Skirts/CAD/Smol_Hex_Skirts_Micron180.step
310.5 x 320.2 x 55.4 mm
Front_rear_skirt_trim_180
Rear_Skirt_180
Side_Skirt_120 x 2
Skirt_Logo x 2
Side_Skirt_Accent x 2
Z_Motor_Cover x 4

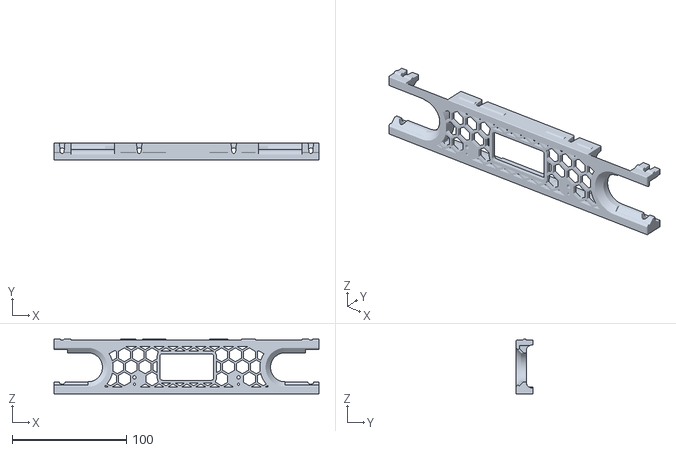
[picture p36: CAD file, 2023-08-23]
Micron+/Smol Hex Skirts/STLs/Front - 3.5 Touchscreen/Smol_Hex_Front_Skirt_35_Touch_Screen_v3.stl
231.6 x 15.0 x 48.0

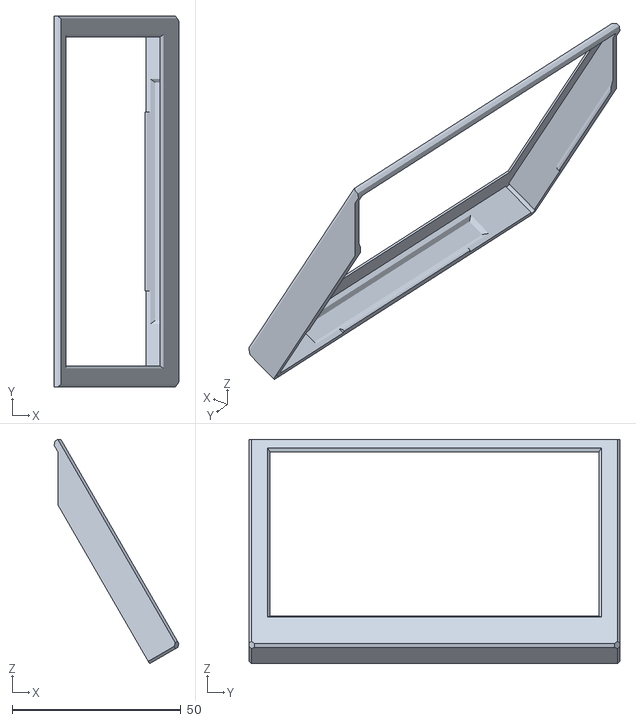
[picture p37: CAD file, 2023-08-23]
Micron+/Smol Hex Skirts/STLs/Front - 4.3 Touchscreen/(a)_Smol_Hex_Front_Skirt_43_Touch_Screen_Faceplate.stl
37.0 x 110.0 x 66.5

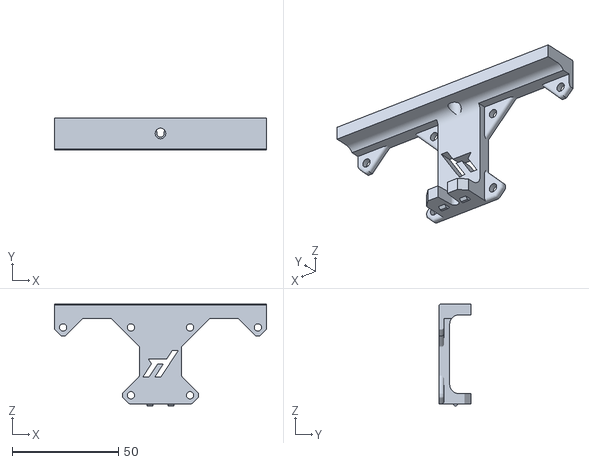
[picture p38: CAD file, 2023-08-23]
Micron+/Smol Hex Skirts/STLs/Optional/Optional_Fan Support_No Recess_x2.stl
100.0 x 15.0 x 48.0

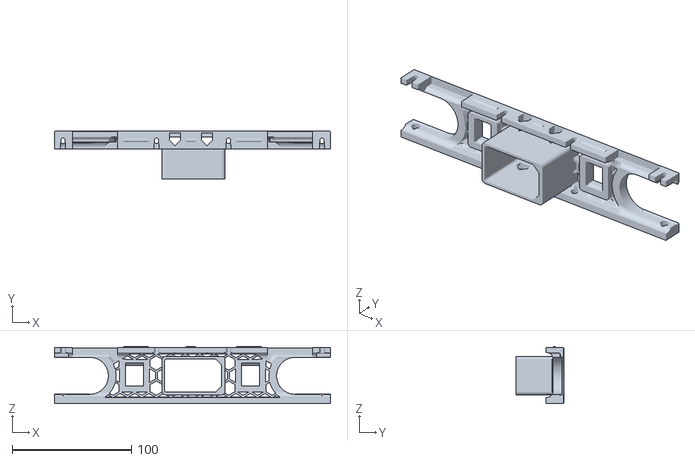
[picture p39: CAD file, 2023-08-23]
Micron+/Smol Hex Skirts/STLs/Rear - Dual Keystone/Smol_Hex_Rear_Skirt_Dual_Keystone.stl
231.6 x 40.0 x 48.0

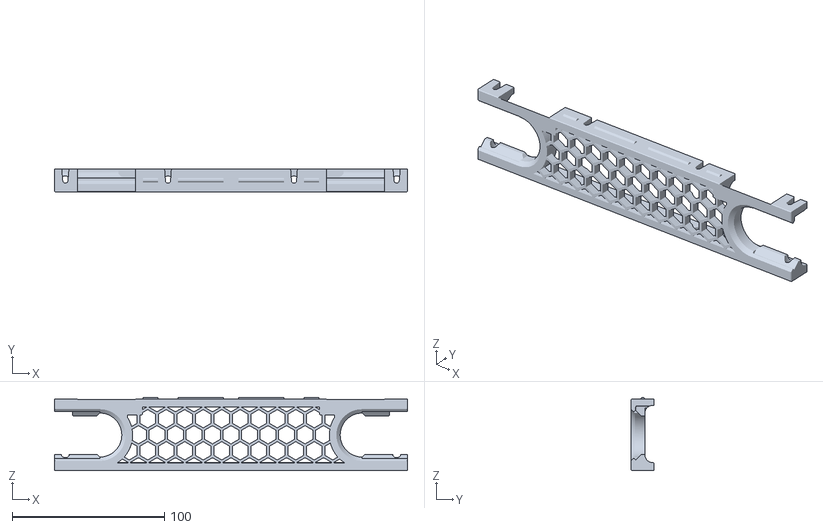
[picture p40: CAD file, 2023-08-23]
Micron+/Smol Hex Skirts/STLs/Stock/Smol_Hex_Front_Skirt.stl
231.6 x 15.0 x 48.0

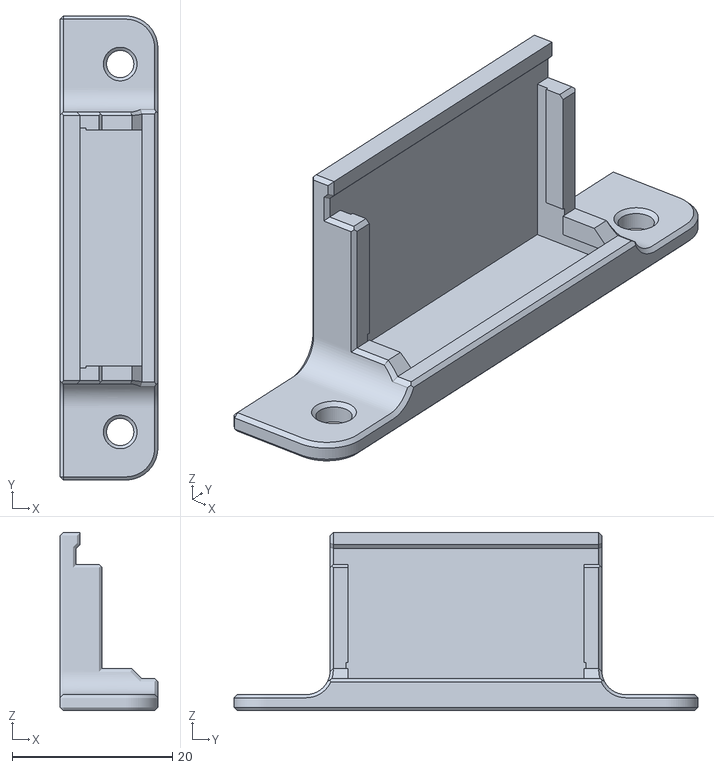
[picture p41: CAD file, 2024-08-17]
Micron+/WAGO_221-415_1515_Mounts/1515 Mounts (No Panel Clearance)/STLs/[a]_1515_1x_WAGO-221-415_mount.stl
12.2 x 57.9 x 22.3

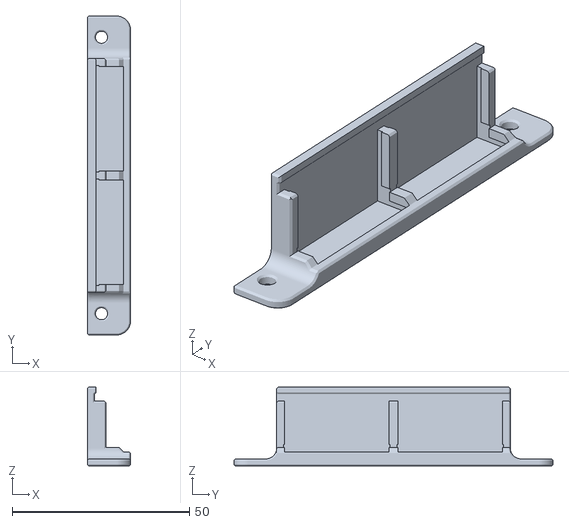
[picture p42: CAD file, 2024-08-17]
Micron+/WAGO_221-415_1515_Mounts/Micron Electronics Bay (3mm Panel Clearance)/STLs/[a]_Micron_1515_2x_WAGO-221-415_mount.stl
12.2 x 89.9 x 22.3

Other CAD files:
Micron+/Z Covers_Cable Access/[a]_Z_Belt_Cover_Cable_b_x2.stl
Micron+/Z Covers_Cable Access/CAD/Z Drive Belt Cover_Cable_Access.step
Micron/Micron/AntHead_NH36 Mount/STLs/18mm Standoff/[a]_Spacer_R_18mmStandoff_x1.stl
Micron/Micron/AntHead_NH36 Mount/STLs/20mm Standoff/[a]_Spacer_L_20mm_Standoff_x1.stl
Micron+/KGLM Hex Z Joint/[a]_Z_Joint_Hex__No_Logo_x4.stl
Micron+/MDC/STLs/Heatset Version/Bottom_Hinge_Door_Mount.stl
Micron+/MDC/STLs/Heatset Version/Bottom_Left_Door_Corner.stl
Micron+/MDC/STLs/Heatset Version/Drill Guides/Drill_Guide_BL.stl
Micron+/MDC/STLs/Heatset Version/Drill Guides/Drill_Guide_BR.stl
Micron+/MDC/STLs/Heatset Version/Drill Guides/Drill_Guide_Handle.stl
Micron+/MDC/STLs/Heatset Version/Drill Guides/Drill_Guide_TL_1mm.stl
Micron+/MDC/STLs/Heatset Version/Hinge_Frame_Mount_x2.stl
Micron+/MDC/STLs/Heatset Version/Top_Hinge_Door_Mount.stl
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

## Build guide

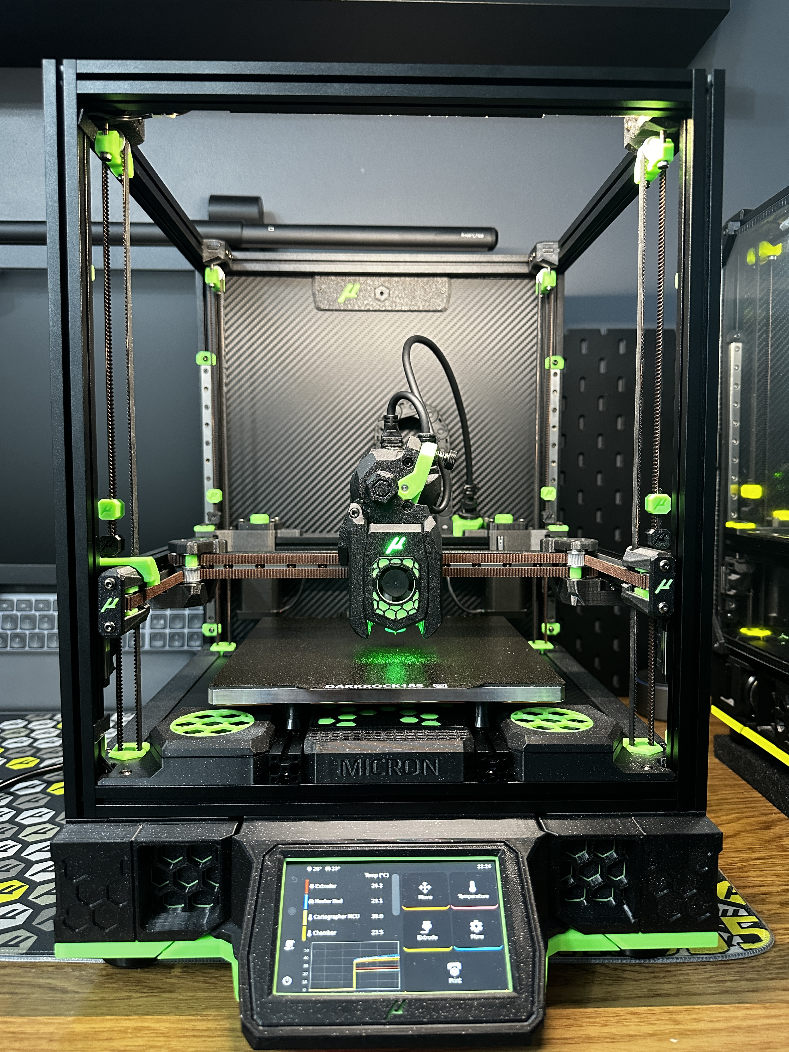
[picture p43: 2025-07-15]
Micron/Micron/Display Bezel Border Accent/Images/Printed.JPG

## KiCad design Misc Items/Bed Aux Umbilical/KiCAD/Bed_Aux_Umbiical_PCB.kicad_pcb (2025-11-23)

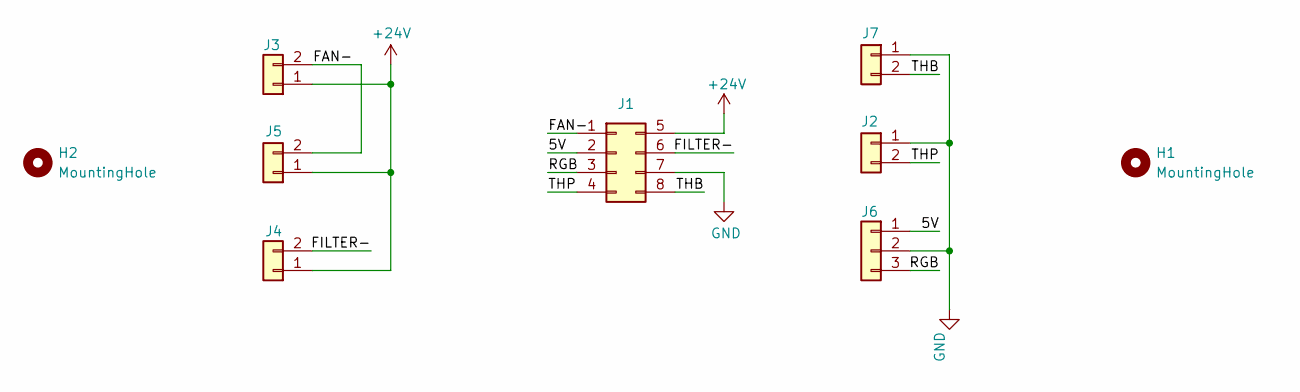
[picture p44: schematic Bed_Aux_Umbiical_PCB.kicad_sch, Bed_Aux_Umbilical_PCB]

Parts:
H1, H2: MountingHole; MountingHoleBare_M3
J1: Conn_02x04_Odd_Even; Molex_Micro-Fit_3.0_43045-0800_2x04_P3.00mm_Horizontal
J2, J3, J4, J5, J7: JST-XHP-02; JST_XH_S2B-XH-A-1_1x02_P2.50mm_Horizontal
J6: JST-XHP-02; JST_XH_S3B-XH-A-1_1x03_P2.50mm_Horizontal

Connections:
+24V: J1.5, J3.1, J4.1, J5.1
/5V: J1.2, J6.1
/FAN-: J1.1, J3.2, J5.2
/FILTER-: J1.6, J4.2
/RGB: J1.3, J6.3
/THB: J1.8, J7.2
/THP: J1.4, J2.2
GND: J1.7, J2.1, J6.2, J7.1

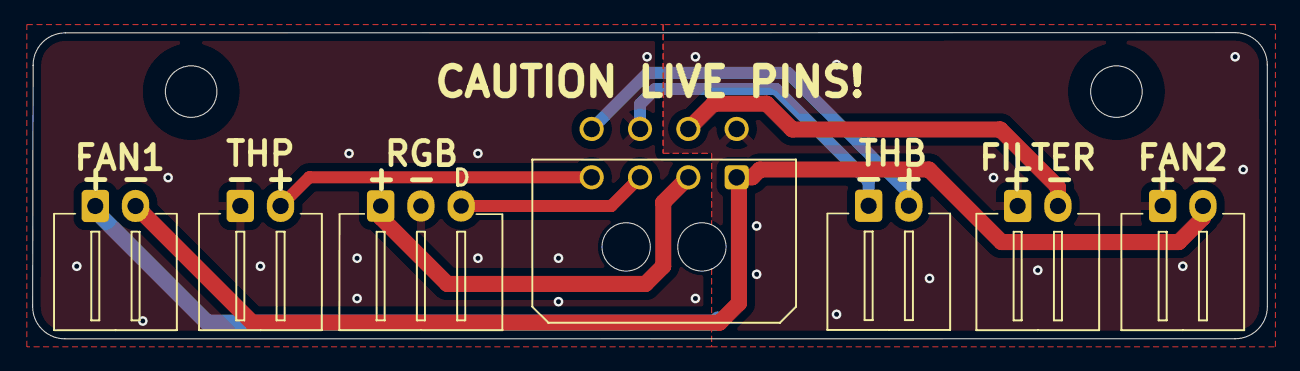
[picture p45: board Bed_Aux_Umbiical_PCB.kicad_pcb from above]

Board: 2 copper layers, 76.6 x 19.0 mm, 9 parts (0 on the bottom side), 8 nets.

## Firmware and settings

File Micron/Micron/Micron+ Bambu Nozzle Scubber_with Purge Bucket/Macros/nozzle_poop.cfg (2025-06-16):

[gcode_macro NOZZLE_POOP]
description: Macro to purge nozzle, then push the extruded filament into the purge bucket.
gcode:

### Positioning Toolhead ###

    M117 Getting ready...
    RESPOND PREFIX=⏱️ MSG="Getting ready..."
    G92 E0                         # Reset extruder
    G90                            # Absolute positioning
    G1 E4.0 F3600                  # Fill nozzle
    G1 Z20 F3000                   # Move nozzle away from bed
    G1 X70 Y172 Z5.0 F5000.0       # Move to start position
    G1 Z0.0 F5000.0                # Move nozzle to bed

### Purging Filament ###

    M117 Pooping...
    RESPOND PREFIX=💩 MSG="Pooping"
    G1 Z3 E10 F60                  # Start slow, to create a good base on the bed
    G1 Z7 E50 F30                  # Continue rising and extruding
    G91                            # Relative positioning
    G1 E-1 F1200                   # Quick retract to relieve pressure
    G90                            # Back to absolute
    G1 Z8 F600                     # Detach cleanly
    M106 S255                      # Turn on PCF
    G4 P7500                       # Cool for 7.5 seconds
    M106 S0                        # Turn off PCF

### Removing purge from bed, into purge bucket ###

    M117 Moving waste to bucket...
    RESPOND PREFIX=🧹 MSG="Cleaning up after purge"
    G1 X93 Y142 F2000              # Move toolhead forward and position PCF duct in front of poop
    G1 Y142 Z0.4 F3000             # Lower toolhead
    G1 Y179 Z0.4 F3000             # Push poop into bucket
    G91                            # Relative positioning
    G1 Z4.6 F1000                  # Move nozzle away from bed
    G90                            # Back to absolute
    G92 E0                         # Reset again after purge

### Confirmation of purge completion ###

    M117 ✅ Purge complete
    RESPOND PREFIX=✅ MSG="Nozzle purge complete"
    

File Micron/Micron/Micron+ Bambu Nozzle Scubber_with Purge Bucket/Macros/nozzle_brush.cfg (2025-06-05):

[gcode_macro CLEAN_NOZZLE]
description: Macro to clean nozzle on Micron R1, using Bambu Nozzle brush & Purge bucket. 
variable_start_x: 126                                                # co-ordinate of right edge of nozzle brush
variable_start_y: 186.5                                              # co-ordinate of y-axis centre of nozzle brush
variable_start_z: 0.0                                                # co-ordinate of z height to use nozzle brush, just below the top of the brush so nozzle is inserted
variable_wipe_width: -33                                             # width of nozzle brush in mm
variable_wipe_qty: 10                                                # number of times to wipe nozzle
variable_wipe_spd: 200                                               # speed to wipe nozzle
variable_raise_distance: 10                                          # amount to raise toolhead after wipe

gcode:
 {% if "xyz" not in printer.toolhead.homed_axes %}                   # check if printer is homed
   G28                                                               # home printer if not already done
 {% endif %}
 
 RESPOND PREFIX=🧹 MSG="Cleaning Nozzle..."                          # display information in console
 SET_DISPLAY_TEXT PREFIX=🧹 MSG="Cleaning nozzle..."                 # displays info
  
 ### Move nozzle to start position ###

 G90                                                                 # absolute positioning
 G1 X{start_x} Y{start_y} F6000
 G1 Z{start_z} F1000

### Wipe nozzle with staggered Y-axis ###
 
 {% for wipes in range(1, (wipe_qty + 1)) %}
   {% set y_offset = 0.5 if wipes % 2 == 0 else -0.5 %}
   G1 X{start_x + wipe_width} Y{start_y + y_offset} F{wipe_spd * 60}
   G1 X{start_x} Y{start_y} F{wipe_spd * 60}
 {% endfor %}
 
 ### Raise nozzle ###

 G91                                                                 # relative positioning
 G1 Z{raise_distance} F1000                                          # move nozzle away from bed
 G90                                                                 # back to absolute
 
 SET_DISPLAY_TEXT PREFIX=✅ MSG="Nozzle cleaning complete"           # displays info
 RESPOND PREFIX=✅ MSG="Nozzle cleaning complete"                    # display information in console

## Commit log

2023-08-23 Initial set up
    [Z Drive Belt Cover_Cable_Access.step, [a]_Z_Belt_Cover_Cable_a_x2.stl, [a]_Z_Belt_Cover_Cable_b_x2.stl]
2023-08-28 Add Z Belt Clamp & KGLM Z Joint
    [KGLM_Hex_Z_Joint.step, Z_Belt_Clip_Micron.step, [a]_Z_Belt_Clip_Micron_x4.stl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]
2023-09-10 Add MDC
    First iteration of MDC (Magnetic Door Corners).
    [Bottom_Hinge_Door_Mount.stl, Bottom_Left_Door_Corner.stl, Drill_Guide_BL.stl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]
2023-09-10 Add heatsets to BOM
2023-09-10 Add correct QTY for heatsets
2023-12-18 added Matchstick Mounts
    [1515_Matchstick_Clip_45.stl, Rainbow_Matchstick_Universal_Mount.stl]
2024-08-17 Upload WAGO 221-415 Mounts
    [Micron_Bed_Stand_Offs.step, [a]_1515_1x_WAGO-221-415_mount.stl, [a]_1515_2x_WAGO-221-415_mount.stl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]
2024-08-17 Upload Micron Electronics Bay WAGO 221-415 Mounts
    [[a]_1515_1x_WAGO-221-415_mount.stl, [a]_1515_2x_WAGO-221-415_mount.stl, [a]_1515_3x_WAGO-221-415_mount.stl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]
2024-08-23 Add ERCF 1515 Mounts
    [ERCF_1515_Mount.step, ERCF_1515_Mount_1mm_Foam_x4.stl, ERCF_1515_Mount_3mm_Foam_x4.stl]
2024-08-23 Update ERCF 1515 Mount Readme
    [ERCF_1515_Mount.step]
2024-10-31 Added F623 Bearing Repacker and updated readme's
    [F623_Bearing_Packer.step, Top_x1.stl]
2024-11-20 Add Micron Purge Bucket
    [Base.stl, Base_No Chain.stl, Brush Holder.stl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]
2025-02-17 Add V0 Mods
    Add V0 Folder
    Add V0 Rear DIN Rail Mounts
    Add V0 Lower DIN Rail Mounts
    Add V0 UHP Mount
    [V0_Rear_DIN_Rail_Mount.step, [a]_V0_lower_DIN_rail_mount_x2.stl, [a]_V0_printed_rear_din_rail_mount_x2.stl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]
2025-06-05 Upload Macros
    Added `nozzle_brush.cfg` & `nozzle_poop.cfg`
    [nozzle_brush.cfg, nozzle_poop.cfg]
2025-06-16 Adding stock Micron base
    [Base.stl, Base_No Chain.stl, Base_Stock_x1.stl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]
2025-06-29 Rep Spring Clean
    - Removed all .DS_store and macOS files
    - Cleaned Up Folders
    - Added Stealth Fan Grills
    - Added Single Piece Skirt Accent
    - Cleaned up all readme.md
    - Added Printer Information table
    [(a)_Smol_Hex_Front_Skirt_35_Touch_Screen_Faceplate.stl, (a)_Smol_Hex_Front_Skirt_43_Touch_Screen_Faceplate.stl, (a)_Smol_Hex_Rear_Skirt_Dual_Keystone_Accent.st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]
2025-06-29 Fix broken links
    [Stealth_Fan_Grill.step]
2025-07-15 Upload Dual Colour Spool Holder
    [R1_SpoolHolder_DualColour.step, R1_SpoolHolder_DualColour_x1.stl]
2025-07-15 Upload Display Bezel Border Accent
    [Bezel_accent_border.step, Bezel_accent_border_x1.stl, [a]_Bezel_logo_insert_x1.stl]
2025-07-20 Upload really useful tool
    [Micron Really Useful Tool.step, Micron Really Useful Tool.stl]
2025-10-04 Upload AntHead NH36 Mount
    [PUG_Mount_A_18mm_Standoff_x1.stl, PUG_Mount_A_20mm_Standoff_x1.stl, PUG_Mount_B_18mm_Standoff_x1.stl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]
2025-10-28 Upload Micron NEMA17
    [A_Drive_Frame_Lower_Pinned_x1.stl, A_Drive_Frame_Lower_Screwed_x1.stl, A_Drive_Frame_Upper_Pinned_x1.stl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]
2025-11-23 Added Brush on Left Variant, and LDO Kit specific parts
    [Base_Stock_L_x1.stl, Base_Stock_x1.stl, Base_boop_L_x1.stl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]
2025-11-23 Uploaded Bed Aux Umbilical
    [Bed_Aux_Umbiical_PCB.kicad_pcb, Bed_Aux_Umbiical_PCB.kicad_sch, Bed_Aux_Umbiical_PCB.step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]
